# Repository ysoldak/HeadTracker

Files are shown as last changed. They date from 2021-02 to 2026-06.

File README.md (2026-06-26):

# Zero configuration auto-calibrating DIY head tracker

Head Tracker runs on [Seeeduino XIAO BLE Sense](https://www.seeedstudio.com/Seeed-XIAO-BLE-Sense-nRF52840-p-5253.html) and [Arduino Nano 33 BLE](https://store.arduino.cc/arduino-nano-33-ble) boards and connects to [OpenTX](https://github.com/opentx/opentx), [EdgeTX](https://edgetx.org) and [ETHOS](https://ethos.frsky-rc.com) radios via either wired (PPM) or wireless (Bluetooth) trainer link.

This project would not exist without [awesome work](https://github.com/tinygo-org/awesome-tinygo) by [TinyGo](https://tinygo.org) community that made [codding in Go for embedded systems](https://github.com/tinygo-org/tinygo) possible!

## Quick Setup

- **Buy** [Seeeduino XIAO BLE Sense](https://www.seeedstudio.com/Seeed-XIAO-BLE-Sense-nRF52840-p-5253.html) board
- **Flash firmware**
  - Plug-in the board to your computer
  - Double tap on `RST` button on the board (little one, near USB-C plug), `XIAO-SENSE` USB drive pops up
  - Download `ht_xiao-ble_x.x.x.uf2` from latest [release](https://github.com/ysoldak/HeadTracker/releases)
  - Copy the file to `XIAO-SENSE` USB drive
  - _Ignore operating system panic about USB drive was not properly ejected -- this is normal and expected_
  - USB drive disconnects itself and reboots (congrats! now you have your head tracker!)
- **Verify it works**
  - Re-connect XIAO BLE Sense board to your computer (Unplug and plug back again)
  - Open https://www.serialmonitor.org in Goggle Chrome browser and Connect to the board
  - Watch Head Tracker prints its status periodically (firmare version, bluetooth address and orientation)
- **Connect to your radio**
  - Pick up your radio with wireless trainer link (PARA, Bluetooth)  
    _all recent FrSky radios have wireless trainer that works; other radios may require [PARA Wireless module](https://www.horusrc.com/en/frsky-horus-x10-para-wireless-module.html) installed_
  - Connect XIAO BLE Sense board as a wireless trainer  
    _learn board's ID via [serial console](https://docs.arduino.cc/software/ide-v2/tutorials/ide-v2-serial-monitor) or by attaching little screen (see below) or by walking with your laptop, radio and board away from other bluetooth sources_
  - [Define mixers in your radio](doc/EthOS.md) from Trainer 1,2 and 3 channels to your desired model outputs  
    _you may want to [scale outputs to match rotation angels of the head tracker and your camera gimbal](doc/RadioConfiguration.md)_
- **Attach Head Tracker to your FPV goggles**  
  _see STL files in "case" folder, screen and button are optional_
- **Calibrate and Setup**  
  _nothing to do here, skip to the next item_
- **HAVE FUN!**  
    - _try our [fpv camera gimbal](https://cults3d.com/en/3d-model/gadget/micro-camera-gimbal-ysoldak) on your favourite model;_  
    - _check out [our shop](https://skygadgets.shop) for other cool gadgets._

## Video Tutorials
- [Connect the head tracker wirelessly to your radio](https://youtu.be/b292hyC5Ctk?t=280)  
  _watch full video to learn how to power the head tracker with a 1-cell lipo battery_

---

<table>
<tr><td>
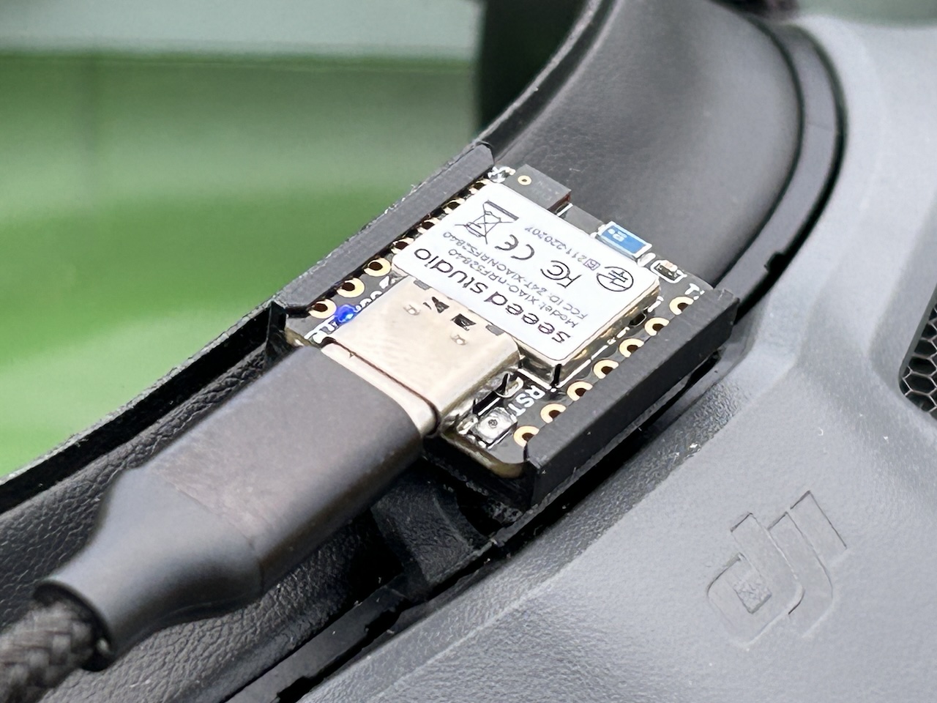
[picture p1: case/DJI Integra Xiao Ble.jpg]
XIAO on DJI Integra

</td><td>
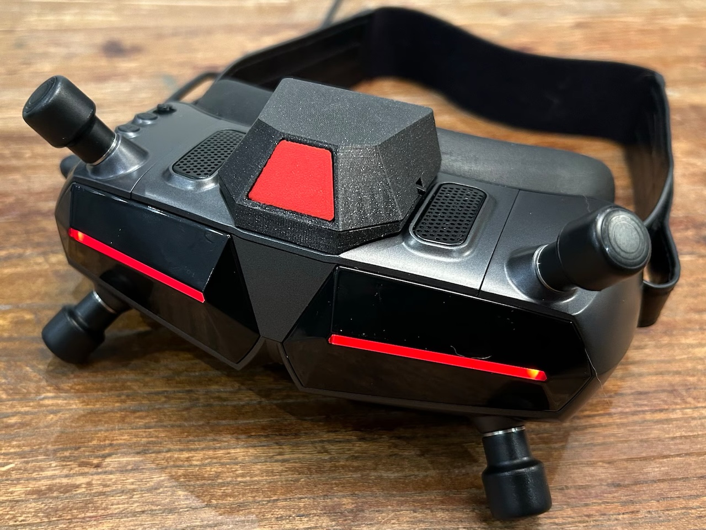
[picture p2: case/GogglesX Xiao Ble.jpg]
XIAO on Walksnail Googles X

</td></tr>
<tr><td>
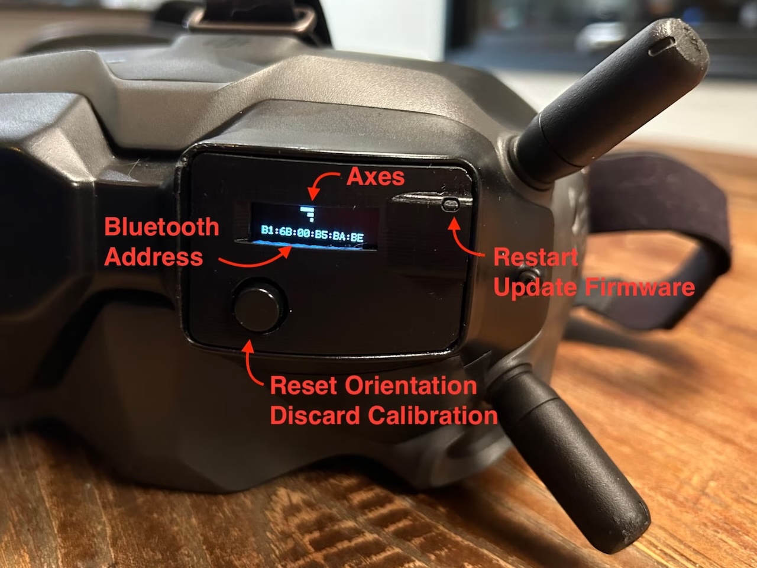
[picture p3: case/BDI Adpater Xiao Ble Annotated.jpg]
XIAO + SSD1306 128x32 on DJI Goggles

</td><td>
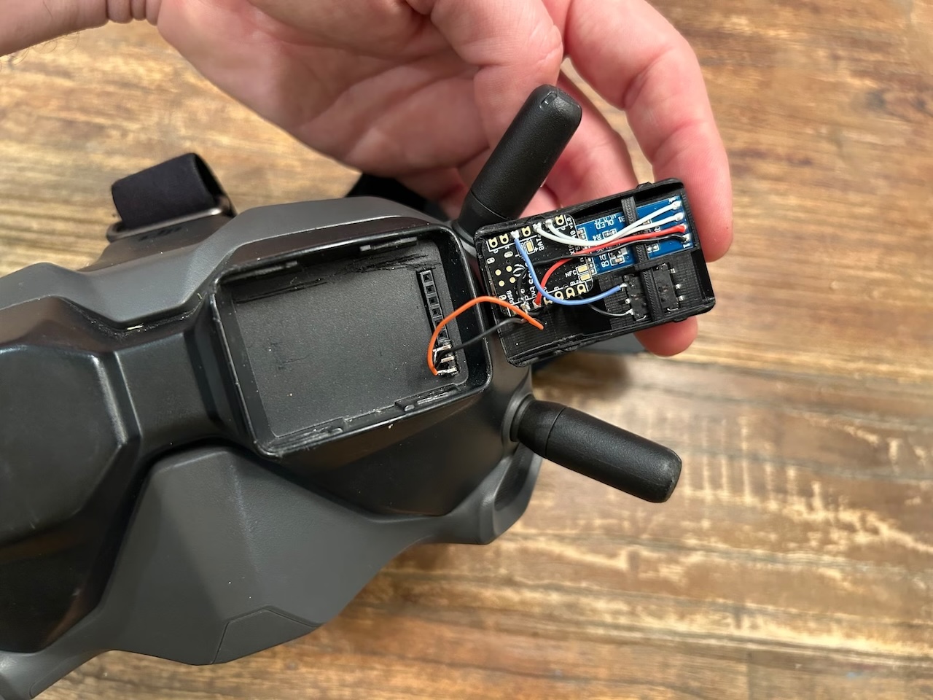
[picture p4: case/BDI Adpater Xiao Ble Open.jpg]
XIAO + SSD1306 128x32 on DJI Goggles, wiring

</td></tr>
</table>

## Camera Gimbal
Check our DIY 3D printed [Micro Camera Gimbal](https://cults3d.com/en/3d-model/gadget/micro-camera-gimbal-ysoldak) and [Low Profile Mod](https://cults3d.com/en/3d-model/gadget/low-profile-mod-for-micro-camera-gimbal) for it!  
Join our dedicated [Facebook group](https://www.facebook.com/groups/242161055041994)  

Also available [fully assembled or as a kit on our shop](https://skygadgets.shop/products/fpv-camera-gimbal-for-micro-servos).

<table>
<tr><td colspan="2">
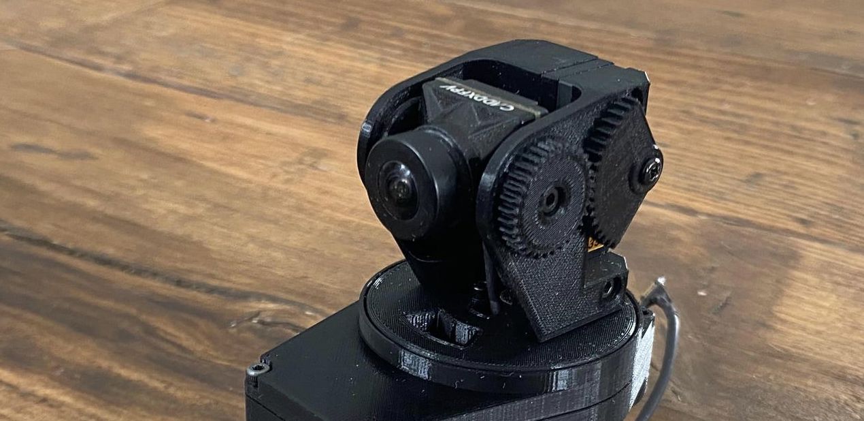
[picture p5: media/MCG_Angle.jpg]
Micro Camera Gimbal, angle

</td></tr>
<tr><td>
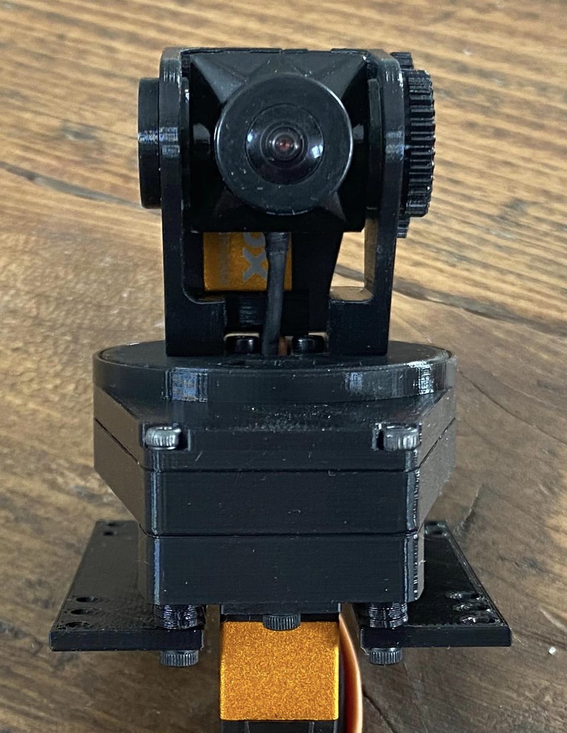
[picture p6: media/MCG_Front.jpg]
Micro Camera Gimbal, front

</td><td>
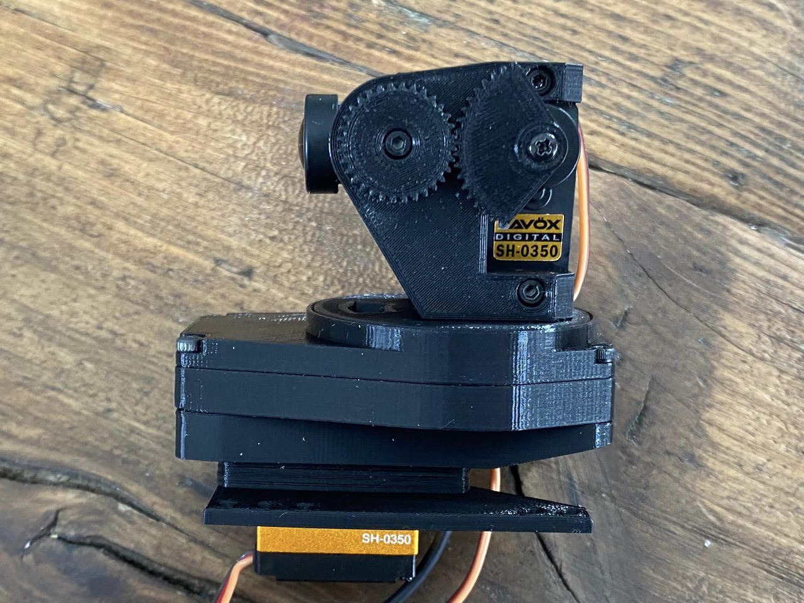
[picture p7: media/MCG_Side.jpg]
Micro Camera Gimbal, side

</td></tr>
</table>

## Tested radios
- FrSky X-Lite Pro (OpenTX)
- FrSky X20S Tandem (EthOS)
- [Radiomaster TX16S can be modified to have wireless trainer link](https://github.com/ysoldak/HeadTracker/discussions/31) and work with the head tracker

## Wiring reference
- **D2**: Orientation reset pin, use a button that connects this pin to **GND**
  - Press the button while head tracker is running to *reset its orientation*
  - Hold the button pressed on the head tracker power up to *factory reset* the board
- **D8**: PPM mode activation pin, solder it permanently to **GND** or use a positional switch
- **D10**: PPM signal pin, connect it to an audio jack tip and **GND** to the jack body
- **SDA&SCL**: I2C communication pins, connect them to 128x32 SSD1306 screen

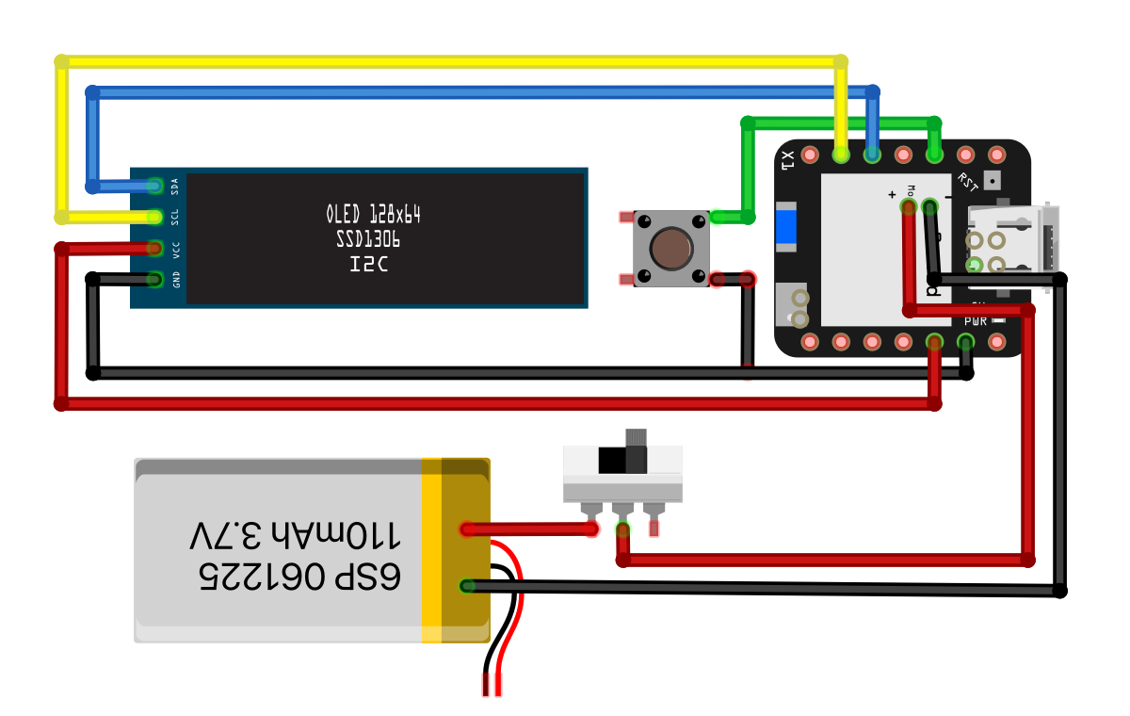
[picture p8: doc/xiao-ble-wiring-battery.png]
XIAO with screen, button and battery wiring diagram

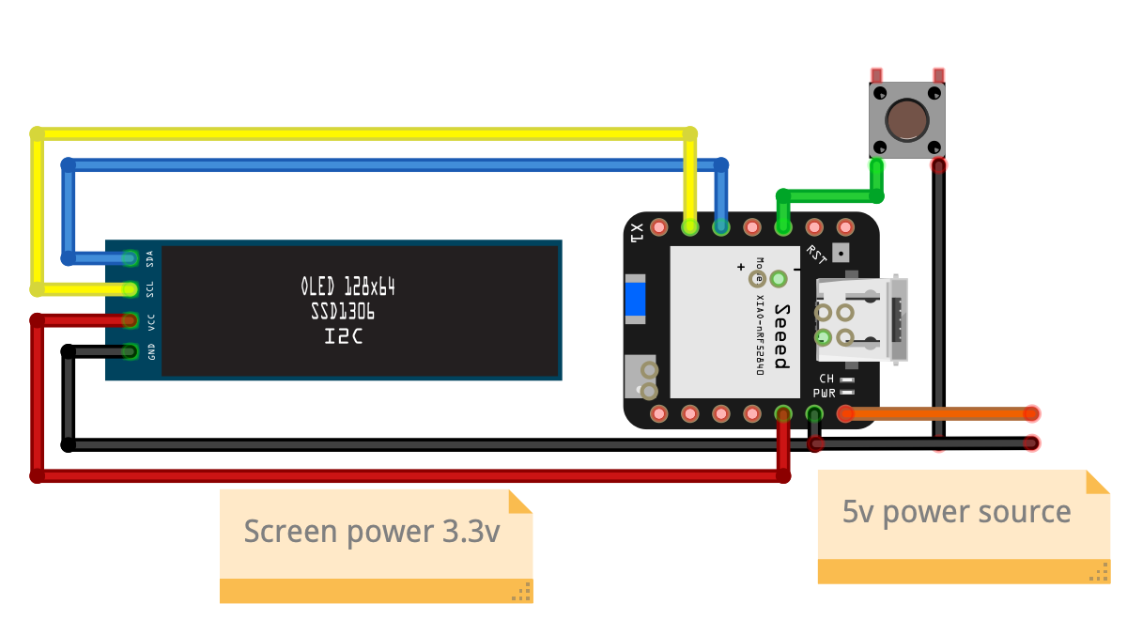
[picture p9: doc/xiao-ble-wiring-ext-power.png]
XIAO with screen and button wiring diagram


## Supported boards

Listed boards are perfect for a head tracker project, since they have both **IMU** for orientation and **Bluetooth** for connectivity.

**XIAO BLE Sense** is a tiny board with UF2 bootloader and SoftDevice (bluetooth driver) pre-flashed that makes it very easy to use.
The board is relatively new and may be harder to find. Please pay attention and order "Sense" variant, it has IMU.  
_Recommended for users w/o experience in embedded programming._

**Nano 33 BLE** is a larger board from Arduino that shall be easier to source. There are two variants of this board: "Nano 33 BLE" and "Nano 33 BLE Sense" -- both will work for this project. This board has no UF2 bootloader pre-flashed and a debug probe is required to flash UF2 bootloader to it.  
_Recommended for advanced users who have a debug probe (JLink or CMSIS-DAP compatible) and can use it._

For a long time, Nano 33 BLE was the only board supported. It has an additional sensor, magnetometer, that head trackers usually use to eliminate pan drift. In practice, however, magnetometer adds more problems than solves. Magnetometer is very sensitive to environment and tricky to calibrate properly. In this project we do not use magnetometer and have a good zero-configuration automatic continuous gyro calibration instead to solve the drift problem. Already after first 5 seconds the calibration is good enough to stop the drift.  

As of now, Nano 33 BLE board does not provide any benefit over XIAO BLE Sense. Instead, the later board is actually easier to use, thanks to pre-flashed UF2 bootloader and smaller size. In the future, just for fun, magnetometer support can be added but only if we can make calibration automatic and transparent for the user.

You have another nRF52840-based board with IMU and want to use it? File a feature request. Better yet, make a PR directly!

## Flash binary

### XIAO BLE Sense (Simple)
Connect the board to your computer, double-tap on RST button and copy `ht_xiao-ble_xxx.uf2` file to XIAO-SENSE usb drive.

### Nano 33 BLE (Advanced)
First, you shall [flash UF2 bootloader to the board](./doc/Nano33BLE.md). You only need to do this once for each new board.
Then connect the board to your computer, double-tap on button and copy `ht_nano-33-ble_xxx.uf2` file to NANO33BOOT usb drive.

## Use head tracker
Attach the head tracker to your FPV goggles.  
Power the head tracker via USB, 1 cell lipo battery or 5v source.  
> Hint: I've been using analog adapter bay on my DJI V1 goggles to source 5v. Now, I source power via USB-C cable connected to DJI Integra.  

### Bare
The head tracker is usable "bare", no extra accessories needed, not even a button.  
To reset the orientation without a button, simply **double-tap** the head tracker.  
> Hint: When the head tracker is mounted on your goggles directly, you can just double-tap your googles in any place to reset the orientation.

### LEDs
On start, board shall blink continuously blue, red and green/orange leds.
- Blue led indicates Bluetooth state and blinks while not connected, it switches to solid blue upon successful connection to your radio (see below);
- Red led indicates initial gyroscope calibration, you shall wait until the red led is off before use, normally no more than several seconds;
- Green/orange led indicates health of the head tracker and shall slowly blink during normal operation.

### Buttons
The head tracker records initial orientation on power up, place your goggles accordingly or reset orientation later by double-tapping the head tracker or by using a **reset orientation** button that can be wired to **D2** and **GND** pins.  
Keep **reset orientation** button pressed on power up to **discard calibration parameters** stored in flash memory.

### Display
If you have a LED `128x32` display added you your board (via I2C), the board's bluetooth address is displayed on it. Blinking ":" symbols indicate bluetooth connection status, like blue led. Upon start, while gyroscope is calibrating, you shall see head tracker version briefly on the screen. The version is then replaced by 3 horisonal bars, one for each axis: pan, tilt and roll.

### Bluetooth remote control (from v2.7.0)

The head tracker can be controlled remotely.  
Use [nRF Connect for Desktop](https://www.nordicsemi.com/Products/Development-tools/nRF-Connect-for-Desktop) or [nRF Connect for Mobile](https://www.nordicsemi.com/Products/Development-tools/nRF-Connect-for-mobile) to connect to your head tracker and send commands or do advanced configuration.

#### Send commands (0xFFC1)

Bluetooth characteristic `0xFFC1` (alt. `0xAFF2`) accepts following one-character commands:
- **Reset orientation** of the board by writing `R` to the characteristic;
- **Factory reset** the board by writing `F` to the characteristic;
- **Reboot** the board by writing `B` to the characteristic.

#### Set device name (0xFFD1)

Set device name by writing up to 16 bytes to `0xFFD1` characteristic.  
Default head tracker device name is "Hello".

#### Configure axes to channels mapping (0xFFD2)

Configure axes to channels mapping by writing 3 bytes to `0xFFD2` characteristic.
First (leftmost) byte configures mapping of the first axis to a channel, and so on. 

Each byte has format: `00IE0OOO`
- `0`   bit is not used,
- `I`   bit for inverted(1)/not inverted(0),
- `E`   bit for enabled(1)/disabled(0)
- `OOO` three bits for channel index offset (0-7),

Examples
- `0x10` means axis mapped to channel 1 (offset 0), enabled,  not inverted
- `0x11` means axis mapped to channel 2 (offset 1), enabled,  not inverted
- `0x25` means axis mapped to channel 6 (offset 5), disabled, inverted
- `0x34` means axis mapped to channel 5 (offset 4), enabled,  inverted

Default mapping: `0x101112` -- first 3 channels, enabled, not inverted

## Connect to radio

HeadTracker can work either in wireless (Bluetooth) or wired (PPM) mode.  
Bluetooth mode is active by default.

### Bluetooth
- Flash your board with a [release file](https://github.com/ysoldak/HeadTracker/releases)
- Connect to the board with a **Serial console** and make note of the board **address** (like: `7b:f5:1e:35:de:94`)
- [SSD1306 LED display](https://www.amazon.com/s?k=ssd1306+128x32+oled+i2c) can be connected (via I2C) to the board; in such case board address displyed there too
- In your radio, select Trainer mode **"Master/BT"**, wait a bit and click "[Discover]"
- Search for your board by address you noted earlier and **Connect** to it
- **Blue led** on the board shall turn **on** indicating successful connection
- Do not forget to configure **Trainer function** in your radio either on "Special Functions" screen of your model or on "Global Functions" of your radio setup.

### Wire
- Activate PPM trainer output by connecting **D8** and **GND** pins.
- Collect PPM signal from **D10** pin. (Audio jack tip shall be connected to **D10** and rest to **GND**)

## Related links
- [DIY-Head-Tracker](https://github.com/kniuk/DIY-Head-Tracker)  
  Original DIY head tracker for Arduino Nano with separate IMU board and PPM over cable
- [RC HeadTracker by Cliff](https://github.com/dlktdr/HeadTracker)  
  Another version of head tracker, based on Arduino Nano 33 BLE board.
- [Bluetooth Smart/BLE Crash Course](https://inductive-kickback.com/projects/bluetooth-low-energy/bluetooth-smartble-crash-course/)
- [Bluetooth low energy Characteristics, a beginner's tutorial](https://devzone.nordicsemi.com/nordic/short-range-guides/b/bluetooth-low-energy/posts/ble-characteristics-a-beginners-tutorial)

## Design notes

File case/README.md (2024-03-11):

## Xiao BLE Sense

The cases designed for Xiao BLE Sense board and SSD1306 128x32 display.  

### BDI Adapter

Head tracker receives power from analog bay.

Print `BDI Adpater Xiao Ble Case.stl` standing on USB-C connector hole side.  
Use double-size tape or a drop of rubber glue to attach the display to Xiao BLE.  
Place carefully little 3D printed boot button into respective place.  
Insert USB-C of Xiao BLE to respective hole and press the display in place.  
Press [Five Directions Navigation Button](https://www.amazon.se/gp/product/B07QM88HP2) into opening.  
Use `BDI Adpater Xiao Ble Lock.stl` to secure button and display.  
Insert power pins into analog bay connectors and insert the case into BDI adapter.

<table>
<tr><td>
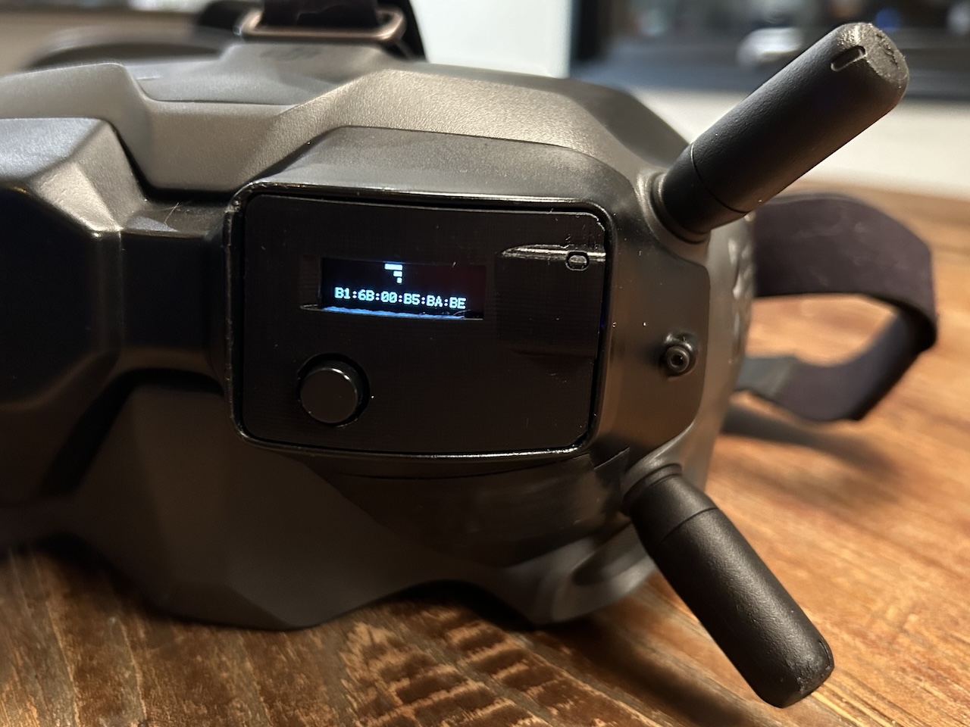
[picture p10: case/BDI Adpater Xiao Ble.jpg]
XIAO + SSD1306 128x32 on DJI Goggles

</td><td>
XIAO + SSD1306 128x32 on DJI Goggles, wiring
</td></tr>
</table>

### Walksnail Goggles X

Head tracker uses 1S battery for power.

Print `GogglesX Xiao Ble Case.stl` and `GogglesX Xiao Ble Base.stl` upside down.  
Insert display, XIAO board, power switch and [button](https://www.amazon.se/gp/product/B08FJ6GDZK) in places.  
Optionally, insert a piece of transparent 1.75mm filament as a light guide for RBG led of XIAO board.  
Add 1S battery, wire it via power switch.  
Close the case and secure with two short M2 screws.  
Place 3D printed orientation reset button cover in place, you may need to adjust the button a bit so click works.  
Attach the case to Googles X with help of double-sided tape.  

XIAO + SSD1306 128x32 on Goggles X

### DJI Goggles 2 / Integra

Head tracker gets power from goggle's USB-C port, connect with 0.25m cable.

Print `DJI Integra Xiao Ble Base.stl` and insert into top head strap loop, can be tight fit.  
Insert XIAO board into the bracket and connect to goggles with USB-C cable.

XIAO + SSD1306 128x32 on Goggles X

### FatShark Goggles

There is also an option to place Xiao BLE board with display on the right side of Fatshark googles.  
Power shall be sourced from googles themselves, 3.3v is available there.

Please check `XiaoBle2.3mf` file and pictures for placement and wiring hints.

<table>
<tr><td>
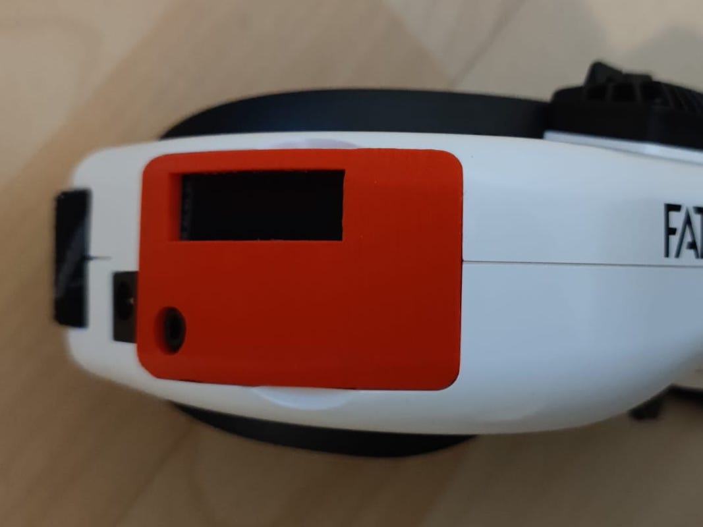
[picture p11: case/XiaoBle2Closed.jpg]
XIAO + SSD1306 128x32 on Fatshark Goggles

</td><td>
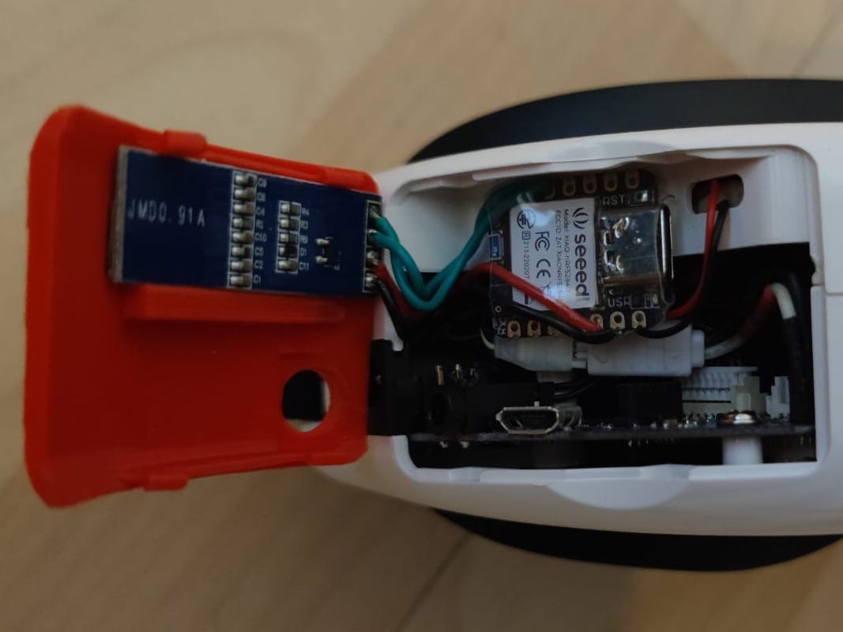
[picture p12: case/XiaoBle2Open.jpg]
XIAO + SSD1306 128x32 on Fatshark Goggles, wiring

</td></tr>
</table>

## Nano 33 BLE

Print `Nano33Ble-Main.stl` on its back, `Nano33Ble-Clip.stl` standing.

`Nano33Ble-Main.stl` has a hole above RGB LED (indicates Bluetooth connection state).  
Insert a piece of transparent fillament into it, for a light guide.

Glue a piece of little something on the case's reboot button (from inside or outside, your preference) to locate it easier.  
Board records orientation on boot, so rebooting is a way to reset orientation, no additional buttons needed.  
Note: Bluetooth connection will break on reboot just to restore quickly after.

Solder 2S balance plug to the board and press-fit it into case -- can power the board from FatShark's battery.  
There is a place for on/off switch, but that's optional.

<table>
<tr><td>
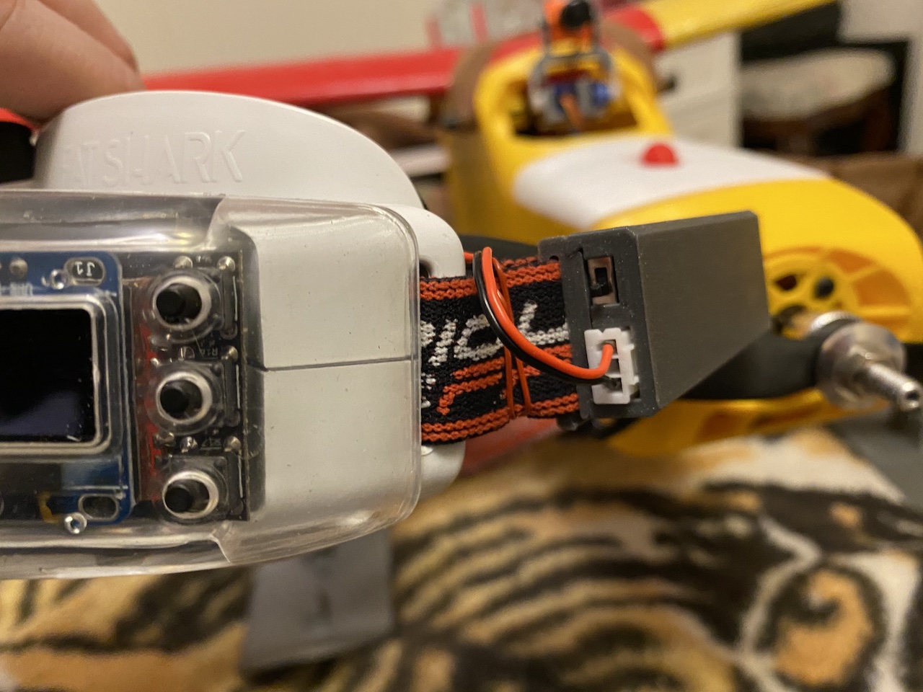
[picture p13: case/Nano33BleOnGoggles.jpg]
Nano 33 BLE on FatShark mounted on the left side

</td><td>
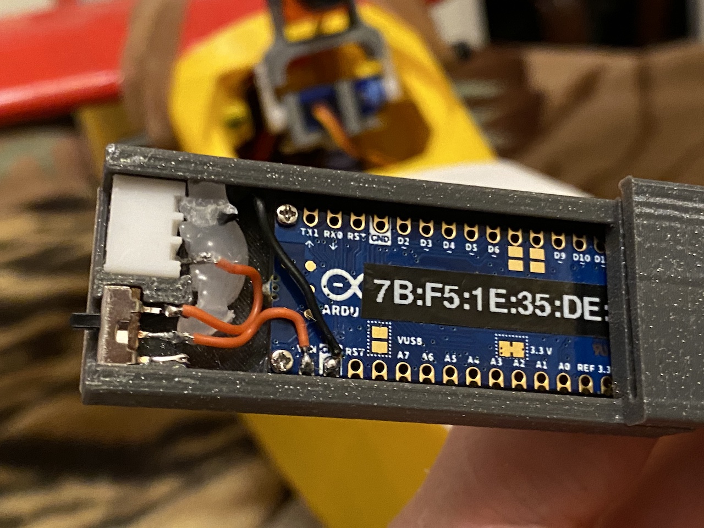
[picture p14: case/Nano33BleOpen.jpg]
Nano 33 BLE on FatShark, wiring

</td></tr>
</table>

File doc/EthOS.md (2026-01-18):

# EthOS 

Full configuration for the HeadTracker and [MicroCameraGimbal](https://cults3d.com/en/3d-model/gadget/micro-camera-gimbal-ysoldak) for [FrSky Tandem X20S](https://www.frsky-rc.com/product/tandem-x20s/) running [EthOS](https://ethos.frsky-rc.com).  

Following assumes you have HT pan servo connected to CH13 and tilt servo to CH14. CH15 is for roll, typically unused.  
HeadTracker runs on XIAO BLE board laying flat on goggles with USB-C facing to the right.  



Note: For HeadTracker mounted some other way `HT TrainerN` mixers will be different, since different trainer channels corespond to different HT axes in that case.  

See also [deep dive article](RadioConfiguration.md) if you want to understand where that % for mixers and outputs come from.

## Mixers

### HT Pot1 (Pan)
```
Name: HT 1
Active condition: Always On
Source: Pot1
Function Type: Add
...
Channels count: 1
Output1: CH13(TR3)
```

### HT Pot2 (Tilt)
```
Name: HT 2
Active condition: Always On
Source: Pot2
Function Type: Add
...
Channels count: 1
Output1: CH14(TR2)
```

### HT Trainer3 (Pan)
```
Name: TR3
Active condition: Always On
Source: Trainer3
Function Type: Add
...
Weight Up: 133%
Weight Down: 133%
...
Channels count: 1
Output1: CH13(TR3)
```
### HT Trainer1 (Tilt)
```
Name: TR1
Active condition: Always On
Source: Trainer1
Function Type: Add
...
Weight Up: 200%
Weight Down: 200%
...
Channels count: 1
Output1: CH14(TR1)
```

### HT Trainer2 (Roll)
```
Name: TR2
Active condition: Always On
Source: Trainer2
Function Type: Add
...
Weight Up: 200%
Weight Down: 200%
...
Channels count: 1
Output1: CH15(TR2)
```

### HT Kill Switch
```
Name: HT
Active condition: SG^
Source: 0
Function Type: Replace
...
Channels count: 3
Output1: CH13(TR3)
Output2: CH14(TR1)
Output3: CH15(TR2)
```

## Outputs

**Attention:** Output ranges must be set in either your Radio or model's Flight Controller, not both!  
If you connect yout pan and tilt servos directly to model's receiver, set output ranges in your radio.  
When pan and tilt servos connected to a Flight Controller, set respective ranges in FC's Outputs tab, leaving radio outputs be 100%.

### CH13 TR3
```
Name: TR3
Min: -150%
Max: 150%
```

## CH14 TR1
```
Name: TR1
Min: -133%
Max: 133%
```

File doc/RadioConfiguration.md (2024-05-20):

# How to configure your radio for the head tracker and a gimbal

### TL;DR
_(For the case of this head tracker and [Micro Camera Gimbal](https://cults3d.com/en/3d-model/gadget/micro-camera-gimbal-ysoldak) with Savöx SH-0350 servos)_  

**Output range pan**: 150% (732-2268us)  
**Output range tilt**: 133% (819-2181us)  
**Mixer weight pan**: 133%  
**Mixer weight tilt**: 200%

**Attention:** Output ranges must be set in either your Radio or model's Flight Controller, not both!  
If you connect yout pan and tilt servos directly to model's receiver, set output ranges in your radio.  
When pan and tilt servos connected to a Flight Controller, set respective ranges in FC's Outputs tab, leaving radio outputs be 100%.

See [EthOS](EthOS.md) article for the full configuration.

---

For the best experience with head tracking, you want your HT and camera be always aligned.
This concerns not only drift, but the deflection angle also.
It is quite annoying when you turn your head 90 degrees to the right and camera travels only 60 degrees same direction.
The opposite is annoying too. Let’s try and see how can we configure your radio to keep HT and camera in sync.

## Facts

Typical micro **servo throw** is `90deg` for standard range 988-2012us and `135deg` for extended range 732-2268us.  
Extended range is standard range multiplied by up to 1.5 and can be configured for any channel in most modern radios.  

Another important factor to keep in mind is **gear ratio** (for geared camera gimbals) for pan and tilt.  
For example, [Micro Camera Gimbal](https://cults3d.com/en/3d-model/gadget/micro-camera-gimbal-ysoldak) gear ratios are `2:1` for pan and `3:2` for tilt.

We shall use [Micro Camera Gimbal](https://cults3d.com/en/3d-model/gadget/micro-camera-gimbal-ysoldak)
with [Savöx SH-0350 servos](https://www.savoxusa.com/products/savsh0350-micro-digital-servo-16-36) in our calculations for the rest of this article.

## Calculations

### Head tracker output
The head tracker’s orientation (`-180` to `+180` each axis) is represented by three channels in standard range (988-2012us).  

### Output range
From servo throws for extended output range and gear ratios we conclude gimbal is capable of delivering `270deg` on pan and `202.5deg` on tilt.  
We do not need that much on tilt though and `1.33` output range shall be enough there giving us `180deg`.  

### Mixer weights
Since we have only `270deg` on pan vs. `360deg` that HT delivers, we need to scale trainer (input) channel for pan in radio so gimbal deflection angle matches the one of the head tracker.  
The pan input channel must be scaled by `1.33(=360/270)` and we do that by setting “`Weight:133%`” for respective mixer in radio powered by OpenTX-like firmware.  
Likewise, for tilt the weight value is `200%(=360/180)`.

## Conclusions and notes

That’s all, folks. Hope this helps you configure you radio for the best head tracking experience!

Note though, the exact values may vary a bit depending on which head tracker and camera gimbal you use and what outputs they are capable of.  
Servo throws can vary for brand, model and even individual servos to some extent. The above numbers shall help you started, adjust them for your case!

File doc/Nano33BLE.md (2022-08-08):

_This information is only actual for Arduino Nano 33 BLE boards, since Seeeduino XIAO BLE ships with UF2 bootloader pre-flashed._

## Flash UF2 bootloader on Nano 33 BLE board

You'll need a JLink \[EDU\] or any DAP-compatible [debugger](https://tinygo.org/docs/guides/debugging/#connecting-a-debug-probe) to flash [Adafruit's nRF52 bootloader](https://github.com/adafruit/Adafruit_nRF52_Bootloader) with soft device on Nano 33 BLE board.

Connect your debugger to the board and execute: `make flash-uf2-bootloader`.

_Tip: by default make uses JLink debugger, but there are `-dap` versions of above commands too._

---

## Optionally use S140 v7.3.0 soft device
_This step is not necessary and is provided for informational purpose only_

Adafruit pre-compiles UF2 bootloader with soft device version 6.1.1 for Nano 33 BLE, while newer (better?) soft device version 7.3.0 is available.

To compile UF2 bootloader with 7.3.0 soft device:
- Clone [Adafruit's nRF52 bootloader](https://github.com/adafruit/Adafruit_nRF52_Bootloader) repository
- Run `make BOARD=arduino_nano_33_ble SD_VERSION=7.3.0 all` to compile bootloader with 7.3.0 soft device
- Connect your board to JLink debugger
- Run `nrfjprog -f nrf52 --eraseall` to erase chip
- Run `nrfjprog -f nrf52 --program <path to arduino_nano_33_ble_bootloader-0.7.0_s140_7.3.0.hex>` to flash you board with bootloader and soft device
- Run `make TARGET=nano-33-ble-s140v7-uf2 flash` to flash HeadTracker to Nano 33 BLE board with 7.3.0 soft device

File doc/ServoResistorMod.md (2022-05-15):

# Increase throw of an analog servo

Common RC servo has throw of 45 degrees, each side (90 degrees total).
Some servos have total deflection of 120 or even 180 degrees, but they are usually expensive and/or hard to find.

And you generally want at least 180 degrees throw for pan (yaw) camera servo.

With this simple mod you can convert almost any analog 90 degrees servo to 180 degrees servo.
The idea is to tirck the servo contol circuit by increasing resistance of the servo potentiometer. 

Steps:
- Disassemble your servo and locate potentiometer;
- Measure resistance between potentiometer outer pins: `R0`;
- Calculate resistance `R1 = R0 * 0.6`;
- Solder an extra `R1` resistor between servo control circuit and each of outer potentiometer pins;
- Done!

Picture shows two 2.2kOhm resistors soldered to 3.7kOhm potentiometer.
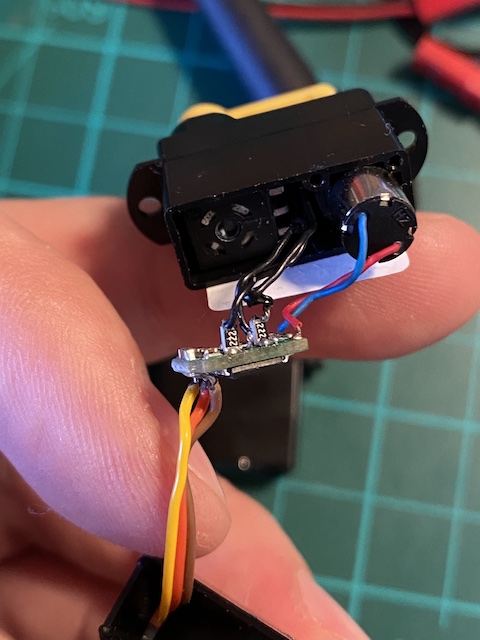
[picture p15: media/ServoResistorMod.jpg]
Servo resistor mod


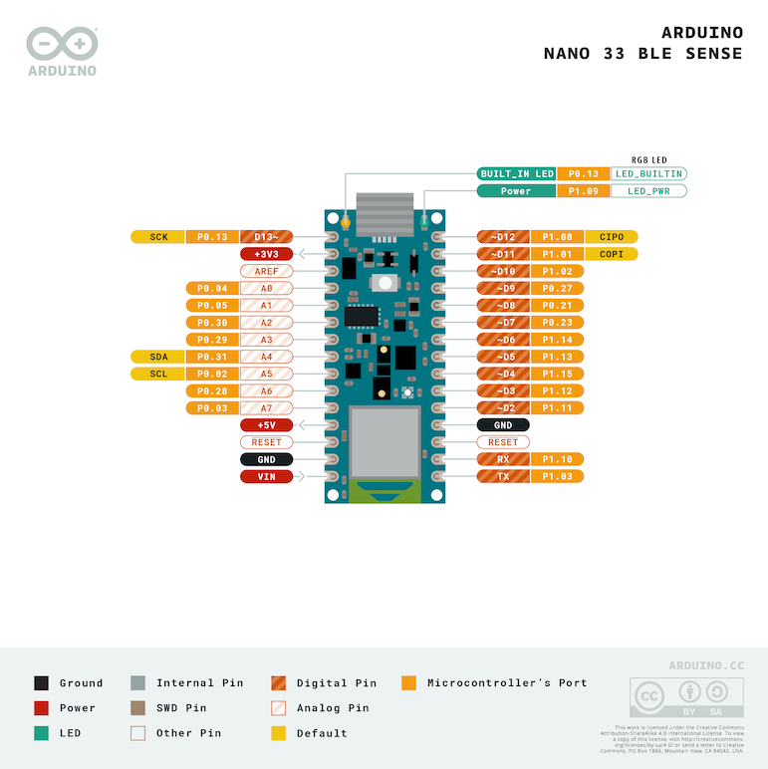
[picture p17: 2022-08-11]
doc/nano-33-ble-pinout.png

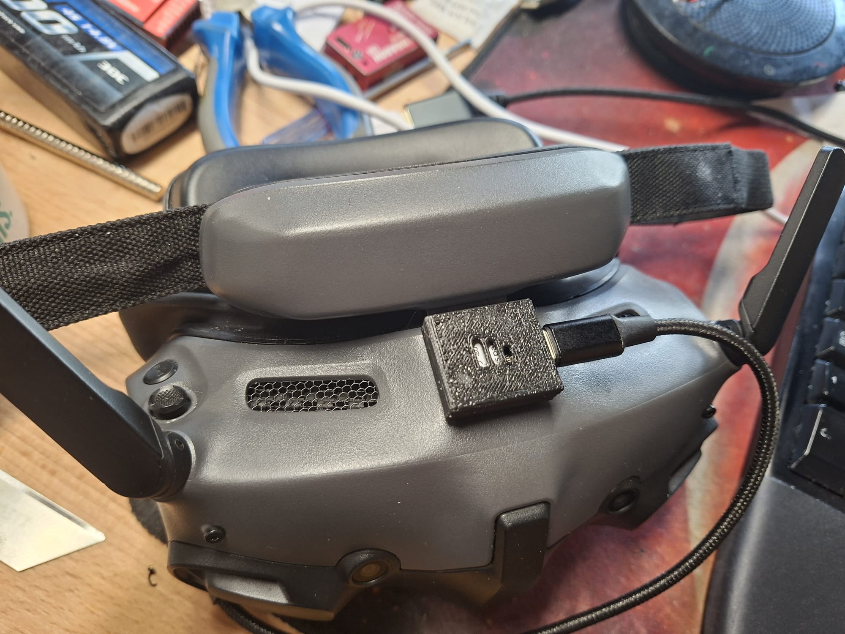
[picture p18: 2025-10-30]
case/xiao-micro-case-dji.jpg

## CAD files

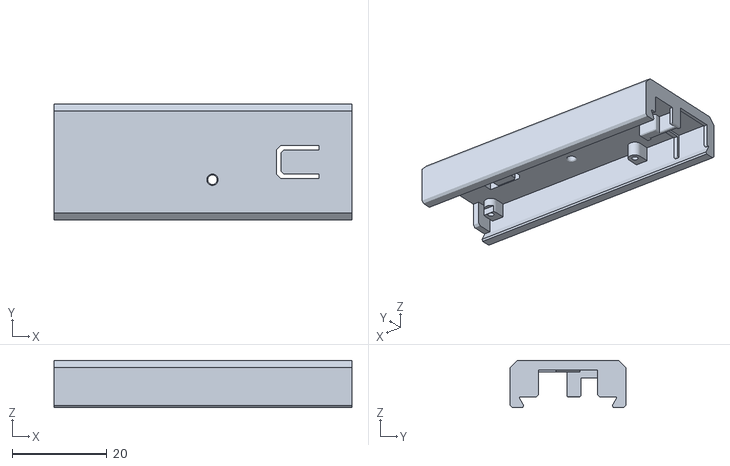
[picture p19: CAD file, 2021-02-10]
case/Nano33Ble-Main.stl
63.0 x 24.5 x 10.0

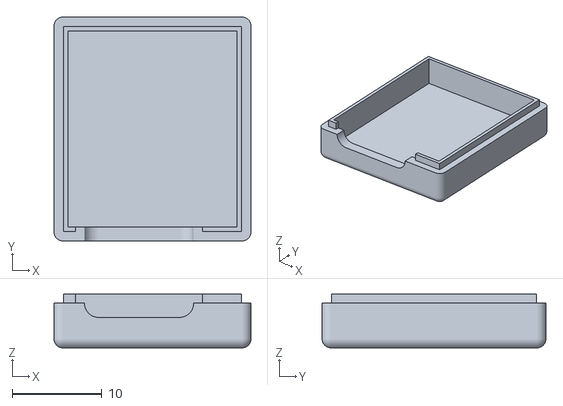
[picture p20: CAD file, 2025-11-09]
case/xiao-micro-case-base-wired.stl
22.0 x 25.0 x 6.00

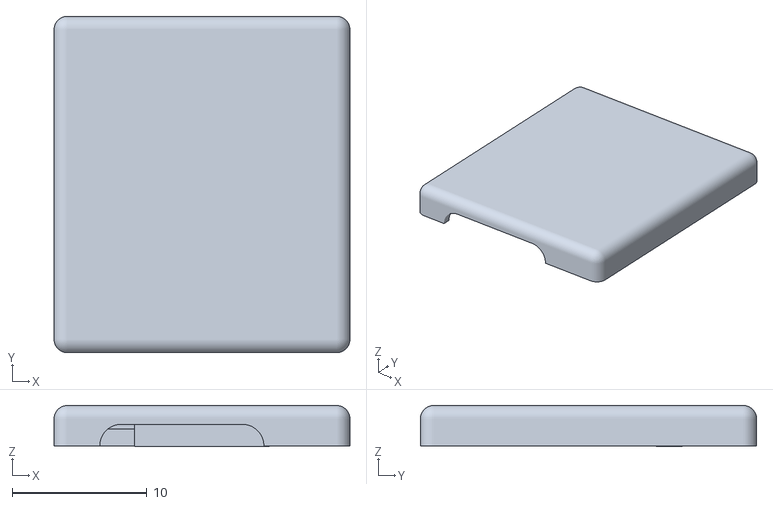
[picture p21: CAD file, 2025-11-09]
case/xiao-micro-case-lid-wired.stl
22.0 x 25.0 x 3.05

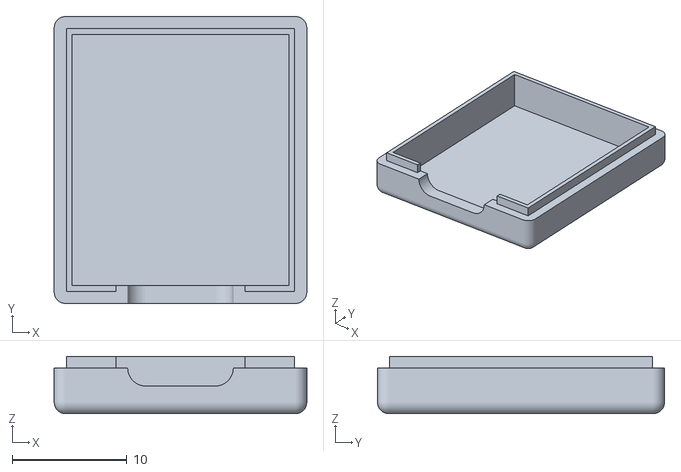
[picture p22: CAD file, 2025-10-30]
case/xiao-micro-case-base.stl
22.0 x 25.0 x 5.00

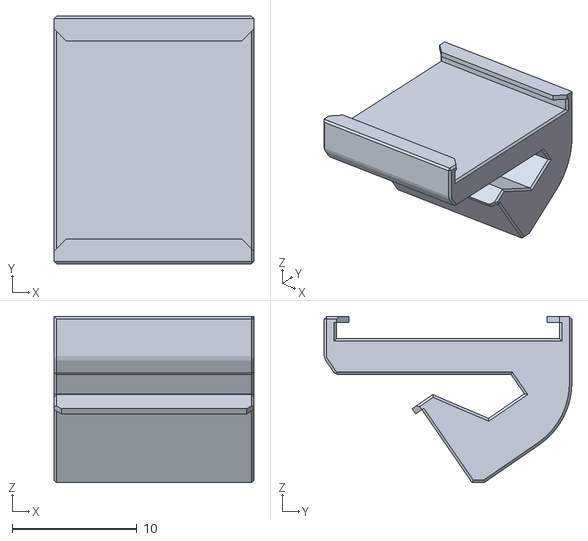
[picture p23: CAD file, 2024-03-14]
case/DJI Integra Xiao Ble Base Forward.stl
16.0 x 19.8 x 13.3

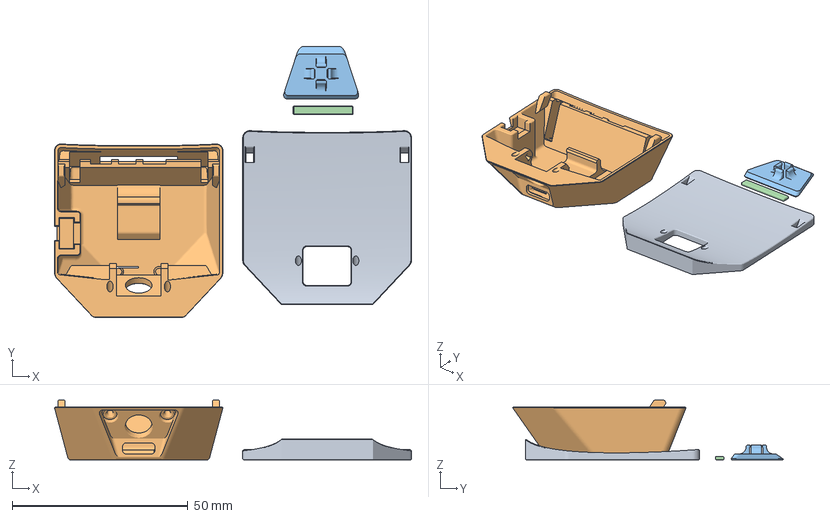
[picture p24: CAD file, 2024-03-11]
case/GogglesX Xiao Ble.3mf
101.5 x 77.0 x 17.0 mm
GogglesX Xiao Ble Base.stl
GogglesX Xiao Ble Case.stl
GogglesX Xiao Ble Button.stl
GogglesX Xiao Ble Lock.stl

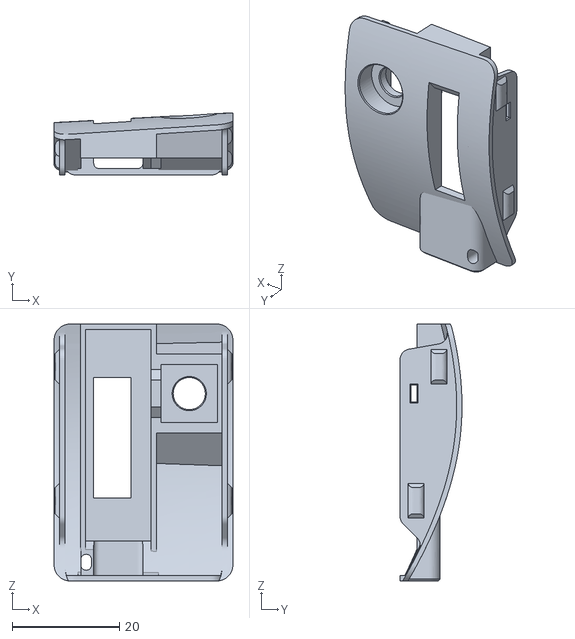
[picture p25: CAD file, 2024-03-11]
case/BDI Adpater Xiao Ble Case.stl
33.4 x 11.6 x 48.0

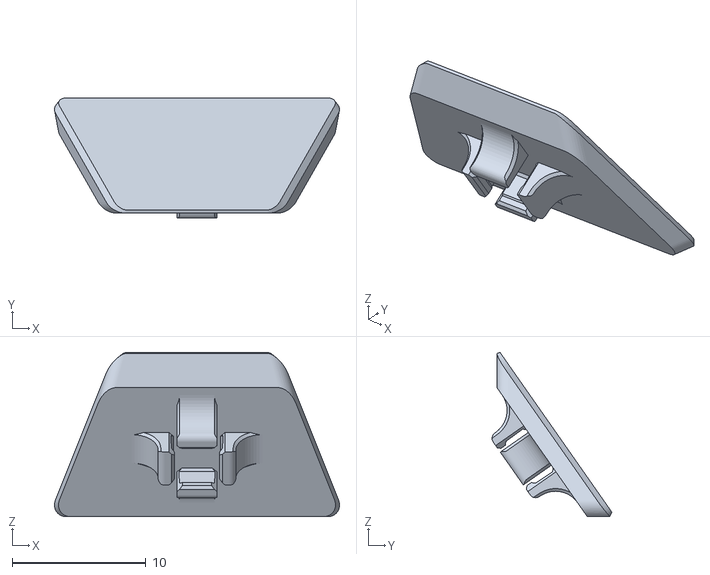
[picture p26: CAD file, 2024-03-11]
case/GogglesX Xiao Ble Button.stl
21.3 x 8.97 x 12.3

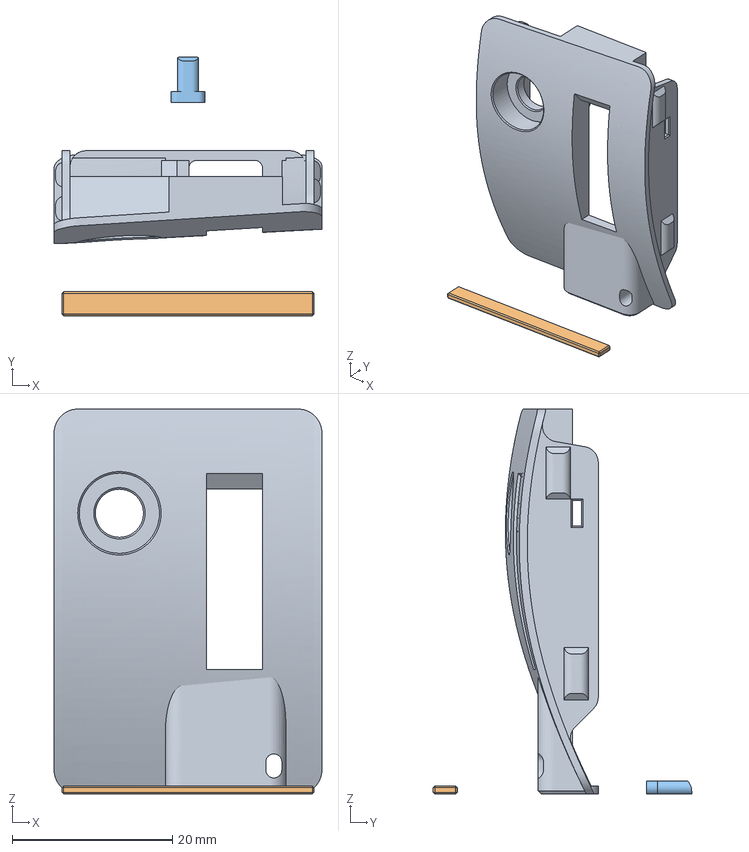
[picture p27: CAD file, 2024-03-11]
case/BDI Adpater Xiao Ble.3mf
33.4 x 32.2 x 48.0 mm
BDI Adpater XIAO Case Body.stl
BDI Adpater XIAO Case Lock.stl
BDI Adpater Xiao Ble Button.stl

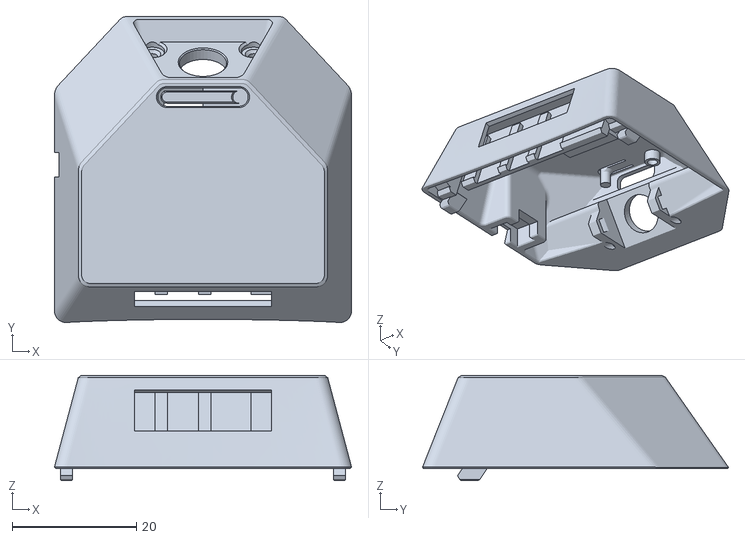
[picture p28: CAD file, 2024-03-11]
case/GogglesX Xiao Ble Case.stl
47.9 x 49.3 x 17.0

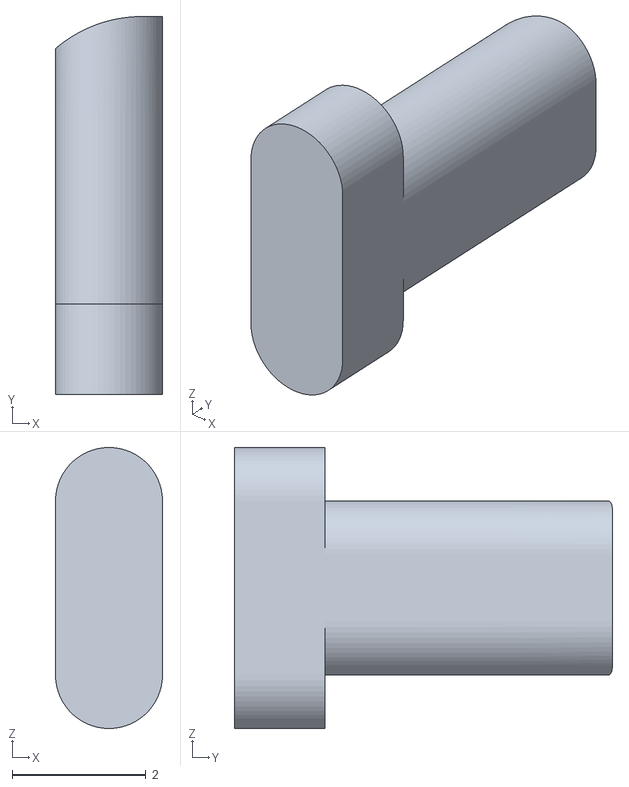
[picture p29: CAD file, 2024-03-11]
case/BDI Adpater Xiao Ble Button.stl
1.60 x 5.65 x 4.20

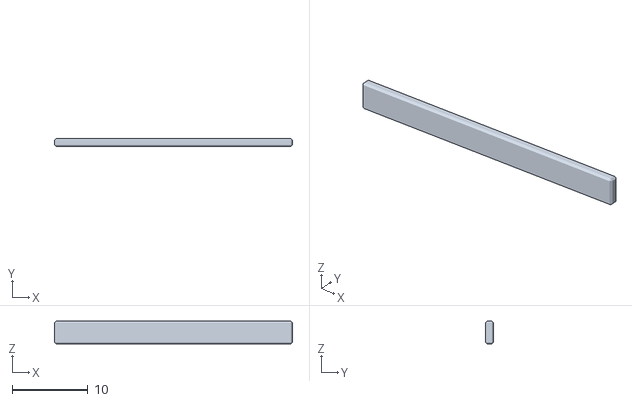
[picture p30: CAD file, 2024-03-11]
case/BDI Adpater Xiao Ble Lock.stl
31.4 x 1.00 x 3.00

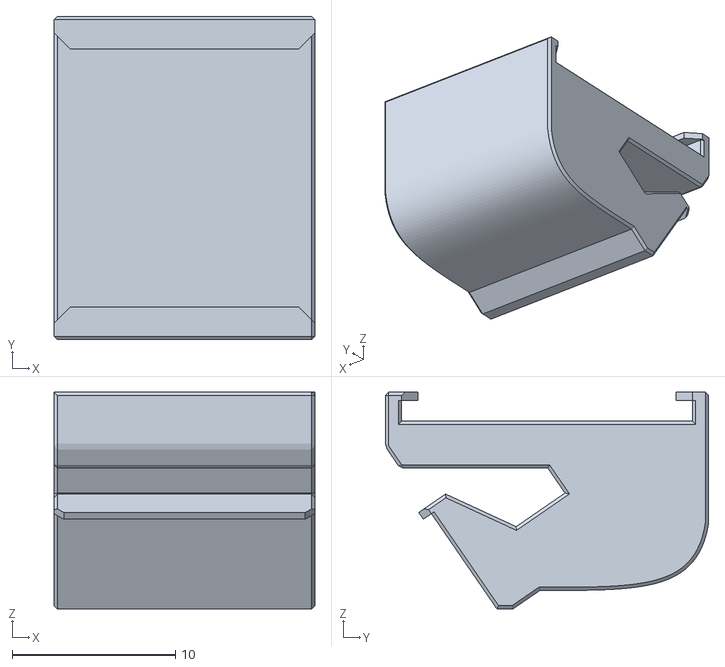
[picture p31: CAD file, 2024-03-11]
case/DJI Integra Xiao Ble Base.stl
16.0 x 19.8 x 13.3

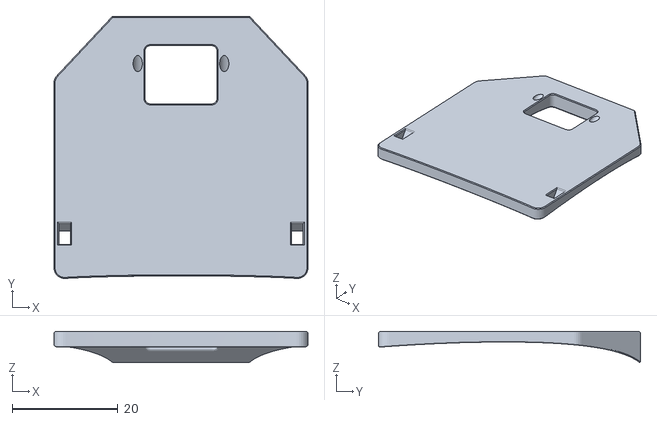
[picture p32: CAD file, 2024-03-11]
case/GogglesX Xiao Ble Base.stl
48.0 x 49.5 x 5.88

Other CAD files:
case/xiao-micro-case-lid.stl
case/GogglesX Xiao Ble Lock.stl
case/XiaoBle2.3mf
case/Nano33Ble-Clip.stl
case/BDI Adpater Xiao Ble.f3d
case/DJI Integra Xiao Ble.f3d
case/GogglesX Xiao Ble.f3d

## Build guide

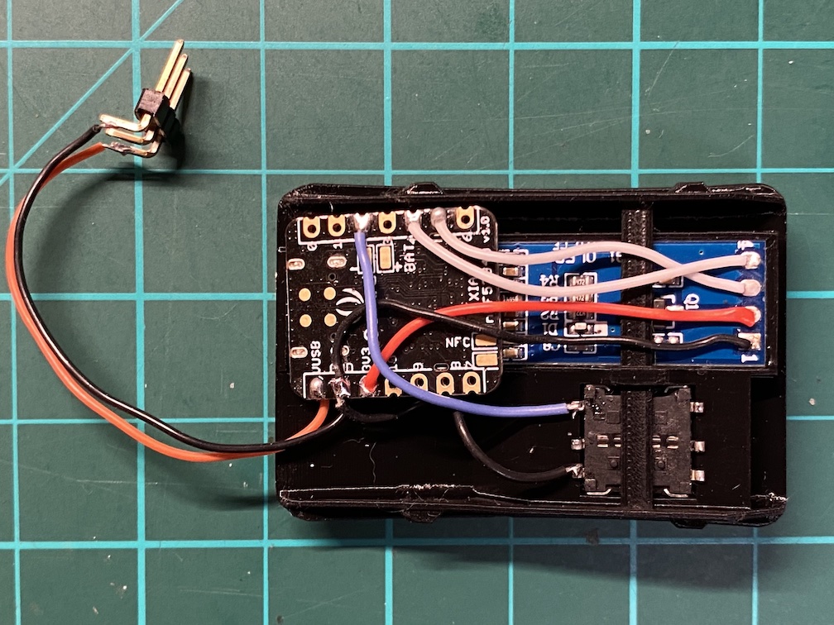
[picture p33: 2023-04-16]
doc/xiao-ble-wiring.jpg

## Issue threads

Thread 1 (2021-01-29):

Calibration routine in the main sketch

ysoldak, 2021-01-29:
Shall be possible to open serial console and initiate calibration.
Eliminates separate sketch.
Start with outputting calibration parameters for copy-paste, make it possible to store in EPROM later.

ysoldak, 2022-05-12:
Not actual anymore after switching to Go

Closed 2022-05-12.

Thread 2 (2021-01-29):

Control via Bluetooth

ysoldak, 2021-01-29:
Since the board has bluetooth, why don't use it for configuration.
Would be handy at field and for calibration "in-situ".

ysoldak, 2021-02-12:
Can perhaps use web_bluetooth
https://github.com/armsp/nano-33-ble-gen/tree/master/bluetooth/web_bluetooth

ysoldak, 2022-08-30:
Not actual anymore, since we target zero-configuration in the HT itself. All adjustment shall be done in user's radio. Or with jumper wires / switches.

Closed 2022-08-30.

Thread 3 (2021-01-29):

Initial pairing is pain

ysoldak, 2021-01-29:
Once connected, it's perfect, can power cycle the board -- it re-connects all good. And stays connected.
But to make the board connect to the radio the first time can be pain.
I expect there are some bugs in ArduinoBLE library that shall be fixed or code in the main loop re-arranged to please FrSky radios.
Shall debug and see.

ysoldak, 2021-02-01:
After some experiments, it seems like Arduino's bluetooth stack is actually OK.

Instead, the radio's bluetooth that may end up in some limbo state if you try to "[Clear]" connection and then connect again in hope to speed up connection after powering off radio and turning it on before a flight.

Just wait, let radio to boot up its bluetooth stack, discover head tracker board and connect to it.
So far, once paired, waiting was the best approach and definitely better than jamming radio with constant requests to clear connection and connect again.

ysoldak, 2021-02-02:
After flashing a new version, board sometimes [changes address](https://github.com/ysoldak/HeadTracker/issues/6) and this breaks bluetooth plairing. No reason to wait for eventual connection (as advised), that will never happen.

Shall be no-issue for day-to-day use (no flashing a new version), but good to keep in mind.

ysoldak, 2022-05-12:
Not actual anymore after switching to Go

Closed 2022-05-12.

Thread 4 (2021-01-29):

Upload STL and STEP files for the board case

ysoldak, 2021-01-29:
I have them, just need to make a final version and upload here (or Thingiverse and link there).

Closed 2021-02-01.

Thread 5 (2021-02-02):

Improve orientation by sensor fusion

ysoldak, 2021-02-02:
[Madgwick](https://github.com/arduino-libraries/MadgwickAHRS) library, for example.

This will use gyro as a base for orientation, fused with accelerometer and magnetometer to fix drift.
https://youtu.be/6qV3YjFppuc

ysoldak, 2021-02-02:
https://courses.cs.washington.edu/courses/cse474/17wi/labs/l4/madgwick_internal_report.pdf

ysoldak, 2021-02-02:
https://blakejohnsonuf.com/project/#IMU

Closed 2021-02-10.

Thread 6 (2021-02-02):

Board sometimes changes address

ysoldak, 2021-02-02:
After flashing new version, the board sometimes changes its bluetooth address (displayed in radio). This breaks pairing and forces operator to do that initial pairing again, and that’s [pain](https://github.com/ysoldak/HeadTracker/issues/3).

This issue affects development, but not regular usage, so kind of low prio, still annoying, would be great to fix this.

ysoldak, 2022-05-12:
Not actual anymore after switching to Go

Closed 2022-05-12.

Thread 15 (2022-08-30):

E73-2G4M08S1C+MPU6500+QMC5883L

01Space, 2022-08-30:
Hi，
Can you add firmware support for e73-2g4m08s1c + mpu6500 + qmc5883l board?
Others have developed a head tracker using ESP + mpu9250 with lower cost.
https://github.com/ScrumPilot616/HeadTracker

ysoldak, 2022-08-30:
No. I don't have the hardware mentioned and cost was never the priority.
Zero configuration, small size, minimum soldering and ease to flash new versions -- these are the priorities of this project.

Closed 2022-08-30.

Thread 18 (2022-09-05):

Feature suggestion: SBUS output signal

MrMap, 2022-09-05:
Regarding HT output formats:
Presently there is BT and PPM; **SBUS** could be an additional format.
SBUS would be useful for all Radiomaster & Jumper users that do not have BT and are OK with a wire connection between HT and radio (servo cable type). They could use SBUS wire connection between HT and radio serial port 1/2 (used as trainer port) - and even power the HT via the very same wire (supply HT power from radio serial port).

Two benefits over PPM:
Digital serial protocol - no jitter.
HT power can supplied without need of USB.

Here is some info on the SBUS serial protocol:
https://github.com/uzh-rpg/rpg_quadrotor_control/wiki/SBUS-Protocol

Nice to know:
For test purposes this gadget, found in many RC pilots toolbox, can display the values transmitted on all the SBUS channels:
https://www.isdt.co/down/pdf/BG-8S_en.pdf

ysoldak, 2023-06-14:
**Notes harvested from internets**

The SBUS protocol uses an inverted serial logic with a baud rate of 100000, 8 data bits, even parity, and 2 stop bits. The SBUS packet is 25 bytes long consisting of:
```
	   Byte[0]: SBUS header, 0x0F
	   Byte[1 -22]: 16 servo channels, 11 bits each
	   Byte[23]
	   Bit 0: channel 17 (0x01)
	   Bit 1: channel 18 (0x02)
	   Bit 2: frame lost (0x04)
	   Bit 3: failsafe activated (0x08)
	   Byte[24]: SBUS footer
```
Note that lost frame is indicated when a frame is lost between the transmitter and receiver. Failsafe activation typically requires that many frames are lost in a row and indicates that the receiver has moved into failsafe mode. Packets are sent approximately every 10 ms or 20 ms, depending on the system configuration.

Note on CH17 and CH18: Channel 17 and channel 18 are digital on/off channels. These are not universally available on all SBUS receivers and servos.

FrSky receivers will output a range of 172 - 1811 with channels set to a range of -100% to +100%. Using extended limits of -150% to +150% outputs a range of 0 to 2047, which is the maximum range acheivable with 11 bits of data.

Because SBUS is a digital bus format, it is an excellent means of receiving pilot commands from a transmitter and an SBUS capable receiver. If SBUS servos are used in the aircraft, SBUS is also an excellent means of sending actuator commands - servo commands can often be sent with lower latency and, by only using a single pin to command up to 16 servos, additional microcontroller pins are freed for other uses.

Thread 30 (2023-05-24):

A noob question about battery

donne1226, 2023-05-24:
I wanna make it without the screen.
What is the hourly power consumption？ I wanna use it about 6 - 10 hours. Can you recommend what the battery capacity should be?

dlktdr, 2023-05-24:
This sounds very familiar to an issue I had with the our firmware in the past if the module you have in your radio isn't the PARA module. If you have the older non-para module it will connect but no data is sent. The older module required encryption to be enabled.

Yuri, here is all the info we found on that issue https://github.com/dlktdr/HeadTracker/issues/22 including some Bluetooth scans.

Although if this is the case then it probably never would have worked even once. Just a thought :)

donne1226, 2023-05-25:
Yes Cliff, I am using the Frsky non-PARA module.

I am sure it worked a few times because I can see value changes on the trainer page. When I did the range test, the radio played 'trainer signal lost' and 'trainer signal recovered'. by the way, I found that the connection range is very short and disconnects at less than one meter.

ysoldak, 2023-05-25:
> by the way, I found that the connection range is very short and disconnects at less than one meter.

I’d assume the board has real tiny antenna and not designed for longer distances.
In my experience the range was more like two meters or so. But then, I don’t see that as a problem, why would your goggles be more than a meter away from your radio :)

ysoldak, 2023-05-25:
Alright, so apparently there are more than one type of bluetooth module that can be installed in radios.

The correct one (works with this head tracker and equal to installed in recent FrSky radios) is called [PARA Wireless Module](https://www.horusrc.com/en/frsky-horus-x10-para-wireless-module.html).

And this is [WRONG module](https://www.horusrc.com/en/frsky-transmitter-horus-x12s-bluetooth-module.html), do NOT buy and install it, will not work, at least not with this head tracker.

donne1226, 2023-05-26:
Alright then.  Thanks anyway. Using such a small board for the head tracker is a great idea！

ysoldak, 2023-05-26:
You can still use XIAO with your radio, two options:
- use `PPM` (wired connection)
- use `Arduino Nano 33 BLE` on the radio side as a helper module (from Cliff's project), HT will connect to it wirelessly (same protocol) and helper module will connect to your radio via SBUS or PPM.

dlktdr, 2023-05-26:
@donne1226 You could also replace the module in your radio with an ESP board (Wroom32, pico32 or c3mini). You can flash some code that emulates the PARA module that should work with this Head Tracker too.

I was looking for a way to remove the dependency of using Frsky modules 😉 It's not super easy to remove the module after it's soldered in, so @ysoldak options are probably the better choice if your not up for a bit of a challenge. Code is here https://github.com/dlktdr/BTWifiModule

ysoldak, 2023-05-26:
Nice, @dlktdr !
As a XIAO fanboy, I want to hint on XIAO ESP32C3 board: https://www.seeedstudio.com/Seeed-XIAO-ESP32C3-p-5431.html

dlktdr, 2023-05-26:
👍 Should (... hopefully) just have to change these pin numbers to make it work :) https://github.com/dlktdr/BTWifiModule/blob/245e0557da3e2e1c900752333933942caf901a6d/src/defines.h#L26C1-L27

I don't have one of these yet. Also like the size of the XIAO boards, only have the NRF versions currently. I might have to pick one up. I don't want to get too far off topic here, let me know if you ever give it a try 😉

donne1226, 2023-05-26:
I'm willing to tinker with the XIAO module to make it functional, but I don't think it's suitable for widespread promotion. First, it's a bit too expensive. Second, there are some technical difficulties.

In the past, I made a tutorial video based on Cliff’s project. Lots of people made their own head tracker modules, which was great!

I found this project a few days ago, and the XIAO board is smaller and cheaper than an Arduino. It's perfect for a standalone module with a built-in battery, so we can get rid of all wires. If you can make it work, I believe that more people will use it.

ysoldak, 2023-05-26:
Yes, I can try, have couple of such boards here and can test it by plugging in to PPM on my radio.

ysoldak, 2023-05-26:
FYI, gentlemen, to make information we discussed here more visible, I've created a [discussion with options for people w/o built-in PARA module](https://github.com/ysoldak/HeadTracker/discussions/31).

Closed 2023-05-26.

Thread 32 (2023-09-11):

Enhancement request for higher battery charge current using Seeed Sense board

puresims, 2023-09-11:
The Xiao BLE has a built in charger for a lipo, but it default charges at 50ma. It can be made to charge at 100ma but has to be done in code.

From the seeedstudio wiki ref: [HERE](https://wiki.seeedstudio.com/XIAO_BLE/?fbclid=IwAR0pTvYtI4JhvGIhpe3tak5j41LQMdeb710NNxy9-Qd78alAKXI8TqYHG3c)

**Battery Charging current**
The battery charging current is selectable as 50mA or 100mA, where you can set Pin13 as high or low to change it to 50mA or 100mA. The low current charging current is at the input model set up as HIGH LEVEL and the high current charging current is at the output model set up as LOW LEVEL.

**Low Charging Current**
```
void setup(){
pinMode (P0_13, OUTPUT);
}
void loop() {
digitalWrite(P0_13, HIGH);
}
```

**High Charging Current**
```
void setup(){
pinMode (P0_13, OUTPUT);
}
void loop() {
digitalWrite(P0_13, LOW);
}
```

ysoldak, 2023-09-11:
Guys, you can try a binary build that shall enable high charge current. Let me know if it works as expected.
Download "binaries" here: https://github.com/ysoldak/HeadTracker/actions/runs/6151924908

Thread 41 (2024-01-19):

Show battery state

ysoldak, 2024-01-19:
Since many assemble this head tracker with 1S LiPo battery, it would be beneficial for them to see battery state.

We can show battery state on boot splash screen and on normal operation screen.

Closed 2024-01-20.

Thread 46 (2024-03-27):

Configuration via Original HeadTracker GUI

bishko, 2024-03-27:
Is it possible to have a firmware that would be compatible with the original HeadTracker from @kniuk so that the GUI can be used?

I'm asking this querstion for two reasons:

1) The GUI allows you to chose which channel you want to use for each axis.

2) It allows you to select between a HT transmitter and receiver.

I have installed the Arduino Nano 33 BLE in my radio because and it is working as a receiver, but it is waiting for a transmitter to be able to connect to it and receiver the information. I belive that this does not run the same way or am I mistaken? Since there is no GUI, I don't know how this is configured.

Would be nice if you can clarify these things and maybe make it compatible with the original HeadTracker at least as a trasmitter.

Maybe having two firmware, one for TX and one for RX would also be a great alternative.

ysoldak, 2024-03-28:
Hi @bishko

Short answer: no, not possible, and no plans to implement this.

Long answer:
Let me unpack the short answer here.

I see there is some confusion about different open source head tracker projects we have now.
To my knowledge, here are 3 major HT projects on GitHub:
- [Original DIY Head Tracker](https://github.com/kniuk/DIY-Head-Tracker) by Denis Frie
- [Feature rich Head Tracker](https://github.com/dlktdr/HeadTracker) by Cliff
- [Zero configuration Head Tracker](https://github.com/ysoldak/HeadTracker) by Yurii Soldak, your's truly

Denis Frie started original head tracker project in 2012, it run on Arduino Nano board and requires a separate IMU board connected to the Nano board. It is a wired solution. This head tracker was presented on RC Groups and inspired many, including us with Cliff to try and make our own, improved HTs.

Some time in end of 2020, both me and Cliff had an idea to implement a head tracker on Arduino Nano BLE board: it has both IMU and Bluetooth on board, so no extra soldering was required and, potentially, we could try and connect it to our radios via wireless trainer link (bluetooth). So we naturally joined forces and had shortly had first working version, with both orientation and bluetooth link working!

Almost from start though, we had different visions on how to proceed. I guess, Cliff wanted the best HT that works for everyone, means lots of features, a nice desktop configurator for calibration and settings. The real deal, THE project.

I, on my part, just wanted something simple that works for me (and great if for someone else too), and easy to maintain, very opinionated. I did not want this to become THE project for me, I'd rather go build and fly my planes :D So no configurator app, no manual calibration -- all, unavoidable and minimal, configuration happens in the radio. Then I've added a mini display, because it's fun and a centering button, because why not. But they both are extras, not needed for HT to work.
Then I've switched to XIAO BLE Sense board to 1) simplify flashing with drag-n-drop and 2) because I like how small XIAO is.
XIAO has no magnetometer (compass), that is believed to be absolute necessary to avoid pan drift. Formally speaking it is true, in practice though, the drift can be compensated in software good enough to be unnoticeable during regular 5-15 mins FPV sessions. Without magnetometer, the last reason to have a configurator app (for magnetometer calibration, tedious and unreliable task) disappeared for me.

So, by design, this head tracker project has no configurator and does not support any and will not in the future, it's just against the project's idea/philosophy.

Now, to your actual questions:

1. This HT always outputs on first 3 channels. It is VERY easy to MIX these three trainer channels (TR1,2,3) to any random output channel in radio (I use CH13 for pan and CH14 for tilt). So there is absolutely no reason to have a separate configurator app for that. Please see an [article how you can configure your OpenTX radio to achieve that](https://github.com/ysoldak/HeadTracker/blob/master/doc/EthOS.md). Example is for FrSKY's EthOS, but any OpenTX/EdgeTX radio is basically the same.

2. This head tracker is only a "transmitter", it connects over Bluetooth to a master radio (or any other device) that supports PARA wireless trainer protocol. You may have Arduino Nano BLE connected to your radio that acts as a "receiver". That's fine, you need to configure _it_ to connect to XIAO BLE Sense board running this head tracker firmware. Or Cliff's head tracker firmware, if that is what you prefer.

I hope this clarifies things a bit and answers your questions!
Good luck!

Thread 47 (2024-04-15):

Adding Crossfire protocol?

ProfDrYoMan, 2024-04-15:
Hi,

adding crossfire would allow using ELRS as trainer link from head tracker to radio.

Recent versions of ELRS allow reprogramming RX as TX, so a tiny RX converted to TX could be used on the head tracker.

Edge-TX supports Crossfire as trainer input.

ysoldak, 2024-04-15:
I do not use Crossfire or ELRS myself, so chances are slim I ever implement this.
But I'm happy and open for contributions.

Just for me to have the full picture.
1) We are talking about radios w/o built-in bluetooth or with bluetooth but which does not speak PARA trainer protocol; otherwise no point to implement yet another link.
2) An ELRS receiver flashed and configured as transmitter (TX) will need to be connected to HeadTracker board (XIAO BLE Sense).

What's required from HeadTracker then? How shall it communicate with the ELRS TX board? Shall HeadTracker send data to serial port (RX/TX pins) in Crossfire format?

ProfDrYoMan, 2024-04-16:
Hi there,

1 Yes and no. I guess every TX that understands Crossfire will also understand para. Crossfire as input is only on EdgeTX afaik. So your reasoning is not wrong. Sometimes it is easier to fit an connect a small ELRS RX with ceramic antenna into the TX.
I see that BT is already in head tracker side. So it’s straight forward using BT on TX side.

2 The ELRS RX flashed as TX gets its data over serial in crossfire protocol.

One other project uses this to transmit directly to the gimbal with the ELRS PPM RX directly at the gimbal. With all mixing in the head tracker.

ysoldak, 2024-05-02:
The other project being https://github.com/dlktdr/HeadTracker perhaps?

I want to keep this Head Tracker's code compact and zero-configuration, this means all mixing and scaling have to happen in radio.

ProfDrYoMan, 2024-05-02:
Fully understand. Closing this one.

Closed 2024-05-02.

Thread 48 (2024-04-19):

permanent reset all 35 sec

boomerschnecke, 2024-04-19:
Having installed the latest SW to XIAO Sense board.
Using as Heattracker at Goggles.
Getting all 35sec periodically a reset of the board
Blue LED is switched off and Bluetooth modul at Radio side sets channels to 0 what means, that  Gimbal is resetted for a short time (around 1 sec)
XIOA is restarting and the Gimbal goes back to the needed position
Reproducable behaviour

ysoldak, 2024-04-22:
- Do you use version 2.5.1 from this repository?
- What is your radio transmitter?
- How do you connect head tracker to your radio?

boomerschnecke, 2024-04-22:
*yes, 2.5.1 latest version from your github page https://github.com/ysoldak/HeadTracker
*Radio = Radiomaster T16S
Seeduino XIAO BLE Sense with SW from https://headtracker.gitbook.io/head-tracker-v2.2 via Bluetooth and UART - Trainer Port conncetion

ysoldak, 2024-04-22:
So tell me is this ALL correct?
- On your goggles you have XIAO BLE Sense flashed with this repo FW 2.5.1;
- On your T16S radio you have another XIAO BLE Sense connected to the radio via UART trainer port, this XIAO has Cliff's firmware flashed and configured to run in "helper" or "rx" mode;
- Both XIAO boards do connect and talk via Bluetooth, but connection drops periodically (you say every 35 secs)

ALL this above true?
I, honestly, never tested such setup myself. All my radios have BT module built-in, so 🤷

Does the radio say "trainer lost" and "trainer recovered" when the disconnect happens?

boomerschnecke, 2024-04-29:
I did answer to you last week, but it seems something has gone wrong:
1) yes at XIAO BLE Sense there was the FW 2.5.1 installed (in the meantime I tried to use also the FW from Cliff)
2) yes, at T16s XIAO BLE Sense with SW from Cliff, connected via Bluetooth to XIAO BLE Sense at Goggles2. This one is connected via UARTexternal (AUX1) to the T16S, which is for this two channels in Trainer Mode setup
Thats true of course, otherwise I would not waste my time for giving you this information. I thought this might be interresting for you. From T16s there was coming no information concerning lost trainer of something like this. "Only" a "reset" to 0 for the servos all 35sec

ysoldak, 2024-05-02:
I would think this is the new feature of re-center on double tap misbehaving. Added in 2.5.0
But you say it does this weird stuff every 35 sec, that's really odd.

If you can, try connect a serial monitor (say from Arduino IDE) to the XIAO BLE board on goggles and see what's the output. Also or instead you may try and connect 128x32 little display to the board and see if axes jump there too.

I'm trying to understand where problem is, in this head tracker or in the helper module connected to your radio or somewhere in-between.

boomerschnecke, 2024-05-02:
Sorry, I do not have any of the mentioned additonal equipment available

Thetruesaint, 2024-06-22:
Hi guys!, me and a friend have a similar problem:
Seeduino XIAO BLE Sense with SW 2.5.1
Radio: TX16S MRKII with an ESP32 C3 supermini with proyect: https://github.com/dlktdr/BTWifiModule.git

Exactly 30 sec. after conection, it disconect from radio (Trainer signal Lost) and we see blue led flash again in the Xiao. In my case, some times, it`s reconnect inmidiatly... in my friend case, it always reconnect every 30 sec.

On the serial monitor, we can see axes movement, and no change in the output at the disconection event (86 to 87)

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

We still have to try to exchange Xiaos and see if the problem move or stay with the radio.

ysoldak, 2024-06-23:
@Thetruesaint thanks for report, see similar #52

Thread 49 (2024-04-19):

Is a base for DJI Goggles 2 existing

boomerschnecke, 2024-04-19:
Hi looking for a XIAO Base to be used for my DJI Goggles 2.
Or could I use one of the DJI Integra XIAO BLE Base for Goggles 2?
Could you please provide some detailed photos how this should be mounted and fitted?
Do I have to modify the foam? Or is it possible to use without faom modification?
Thank you

ysoldak, 2024-04-19:
Please see here and respective STL file

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

ysoldak, 2024-04-19:
DJI Integra and goggles 2 is the same. No foam modification needed.

boomerschnecke, 2024-04-19:
Thanks a lot for your quick reply. The issue is, that Goggles 2 is not having this "handle bar" at the top of the Goggles. So there is no possibility to click this "bar" in. Thats why a ask if something additional specially for Goggles 2 is existing. Or do I have to glue it on the foam?
https://store.dji.com/de/product/dji-goggles-2?vid=127611&from=search-result-v2&position=1&total_result=46
https://store.dji.com/de/product/dji-goggles-integra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
Have a look to the top in the middle of goggles

ysoldak, 2024-04-22:
Oh, my bad, I have Integra only and for some reason assumed Goggles 2 have top strap also.
Well, no then, nothing specific exists for Googles 2 yet. Will write here if/when we have a solution.

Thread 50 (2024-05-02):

PPM not working?

ysoldak, 2024-05-02:
Assembling here bug reports from @KPOPRC in no particular order.
Let's track the issue here.

>yuri! great project! did you stop supporting PWM on all the new releases. i can't get any TR signals via pwm from any of your releases. am i doing something wrong?

>Hello! it's looking like a great project. but the only stable release i can find that doesnt crash with in 3 sec, is 2.3.4 with pwm pin grounded. None of the other versions have red and green flashing with solid blue. regardless no head tracking values are making it to any of the TR channels. Did you guys stop supporting pwm? Please help. TR4 the channel goes up to -90%. all other tr channels kind of glitch at -7. when i unplug the trainer cable, i get an audible "trainer single lost". Any version after 2.3.4, no trainer signal is output via pin d10. D8 is grounded.

>Hello! After version 2.4 pwm doesn't recognize via my radio. But all UF2 files have never worked all the way down to 2.5.0. None of the TR channels carry any head tracking values. After 2.4 the board only flashes red. Can you help with this? I'd love to get these 2 head trackers working with pwm as my radiomaster doesn't have bluetooth.

ysoldak, 2024-05-02:
In your messages you probably mean PPM when you write PWM.

Please make sure you ordered correct XIAO board. You want XIAO BLE Sense variant, i.e. the one with IMU.
The cheaper board that is called simply XIAO BLE, without "Sense" in name, it will not work.

KPOPRC, 2024-05-02:
hey. thanks for the reply. this is the sense varient. I believe.

On Thu., May 2, 2024, 5:47 a.m. Yurii Soldak, ***@***.***>
wrote:

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

ysoldak, 2024-05-02:
The issue turned out to be the wrong board indeed. For the head tracker to work, it needs IMU (Inertial Measurement Unit) that is only available on XIAO BLE Sense board. See that little black box down left.

Closing the issue.

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

KPOPRC, 2024-05-02:
thanks for the help. I did notice that even with out the imu. I was still
getting a trainer signal. but for the latest releases no tr signal was out
put. I assume this is still a 'wrong board problem'. I'll let you know how
it goes with the new boards. they'll be here tomorrow. thanks for your
time.

k

On Thu., May 2, 2024, 2:19 p.m. Yurii Soldak, ***@***.***>
wrote:

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

Closed 2024-05-02.

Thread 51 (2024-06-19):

Two Seeeduino XIAO BLE Sense

bodychmarcin, 2024-06-19:
Hi. Is it possible to connect two modules together? one as a transmitter and the other as a receiver installed in TARANIS which sends the received data to the PPM pin?

ysoldak, 2024-06-23:
Not at the moment, not for two XIAO BLE Sense boards.
Some however try to use ESP32 C3 board on the radio side, and have issues unfortunately, see #48 and #52

I'll try and implement receiver on XIAO BLE board, eventually. No time frame though.

bodychmarcin, 2024-06-23:
Lack of time is very understandable for me :-) generally it doesn't have to be the same board, it can be anything else like esp32.  Tracker 2.2 as a receiver was mentioned in some threads, but as a BLE receiver for PPM it is too advanced and I had a problem with it.  I used ESP32 to connect to your firmware with the Xiao board, the connection was not broken even for a moment, and it was running for over an hour.  The problem is that I don't understand and I don't know the uuid structure and data, and therefore I don't know "golang".  That's why I started this thread.  Best regards, my friend.

bodychmarcin, 2024-06-28:
I wrote a program based on opentxbt that connects to seeduino, it works fine, nothing interrupts the connection, I receive data and send ppm.
Question: I'm curious, is it possible to implement client subscription in seeduino?

ESP32 BT Client, GPIO short to Ground -> sends bool (true or false)
XIAO BT server, receives data bool, if true -> Reset orientation

It is more convenient to do this with a monostable rc switch than to take your hand off to tap twice or look for a button soldered to the XIAO GPIO.

RDM3DGit, 2024-06-28:
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

Can you share link to your code?

bodychmarcin, 2024-07-01:
> Can you share link to your code?

I think so, but I would like to wait until ysoldak could create an additional characteristic, e.g. fff7, in which the client can save bool data, if xiao receives true, it will reset the orientation.

ysoldak, 2024-07-01:
Yes, good idea, @bodychmarcin!
Definitely we can have such extension to BT, add a characteristic. This will not be a strict PARA anymore, no problem though, since backwards compatible still.
Any known implementation/characteristic number for reset orientation? So we don't invent a wheel but just follow them?

bodychmarcin, 2024-07-01:
> Tak, dobry pomysł,@bodychmarcin! Zdecydowanie możemy mieć takie rozszerzenie do BT, dodać cechę. Nie będzie to już ścisła PARA, nie ma jednak problemu, ponieważ nadal jest kompatybilny wstecz. Jakiś znany numer implementacji/charakterystyki dla orientacji resetowania? Czyli nie wymyślamy koła, tylko po prostu za nimi podążamy?

I don't know the language, so I have to ask you about it.  I think you can add another number fff7.  What do you think about it?  unless it's a feature outside the Para structure.  I have ESP32C3 and the monostable switch is physically disconnected from the device and connected to the ESP32 GPIO.  if gpio is shorted, I would like it to send a bool to the xiao feature and reset it.  I don't want to take my hands off the radio :-)

ysoldak, 2024-07-01:
Yes, I think I understood you idea, adding one more characteristic shall be no problem.

So, the BT client sets a characteristic value to "true"; HT notices the value and resets its orientation + resets the characteristic value to default "false".

Shall work, need to test, obviously.

bodychmarcin, 2024-07-01:
I'll test it if you make a tag related to it :)

bodychmarcin, 2024-07-02:
I already managed to create a new service with new characteristics to handle the reset so as not to change PARA.  anyway, thanks for your willingness

Closed 2024-07-02.

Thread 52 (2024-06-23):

Continuosly lost and regain trainer conection (BT)

RDM3DGit, 2024-06-23:
Radio type: TX16S MK2 JB edition
Versions used:
- Radio FW: Edgetx 2.10.1 centurion cloud builded with bluetooth flag enabled
- ESP32 C3 Super Mini (Modified definition.h C3Mini URTS pins): cloned github repository, builded it and uploaded via VSCode
Connecting to: Xiao BLE sense HT with 2.5.1 FW

Expected beheavour: Conection between devices stays solid and uninterrupted.

Actual beheavour: Conection stablished perfctly, but after a minute or so the conection is lost and recovered instantanously. This continues to happen every 30 o 40 seconds continusly.

RDM3DGit, 2024-06-23:
C3 super mini terminal output during disconections and reconection:

BTCLIENT: scan start success
Disc BT Address 032BEC51FFBF, RSSI=-75, Addr Type=1
Disc BT Address F66A731161C3, RSSI=-80, Addr Type=1
Disc BT Address 1C72AA9511E4, RSSI=-80, Addr Type=1
Disc BT Address F66A731161C3, RSSI=-84, Addr Type=1
Connecting to F66A731161C3
Unable to connect to F66A731161C3, address not found in storage
I (716620) BTCLIENT: ESP_GATTC_CONNECT_EVT conn_id 0, if 3
I (716620) BTCLIENT: REMOTE BDA:
I (716620) BTCLIENT: f6 6a 73 11 61 c3
I (716620) BTCLIENT: Starting Service Scan
I (716630) BTCLIENT: open success
I (716910) BTCLIENT: update connection params status = 0, min_int = 10, max_int = 10,conn_int = 10,latency = 0, timeout = 70
I (717340) BTCLIENT: discover service complete conn_id 0
I (717340) BTCLIENT: SEARCH RES: conn_id = 0 is primary service 1
I (717340) BTCLIENT: start handle 23 end handle 65535 current handle value 23
I (717350) BTCLIENT: service found
I (717350) BTCLIENT: UUID16: fff0
I (717360) BTCLIENT: Get service information from remote device
I (717370) BTCLIENT: ESP_GATTC_SEARCH_CMPL_EVT
I (717370) BTCLIENT: Attr Count 5
I (717370) BTCLIENT: Found the Trainer Characteristic
I (717380) BTCLIENT: Subscribing for Notifications
I (717390) SETTINGS: Reading settings
I (717390) SETTINGS: Settings Read Successfully
I (717400) SETTINGS: No data differs, not writing to flash
I (717400) BTCLIENT: ESP_GATTC_CFG_MTU_EVT, Status 0, MTU 23, conn_id 0
I (717410) BTCLIENT: ESP_GATTC_REG_FOR_NOTIFY_EVT
I (717450) BTCLIENT: write descr success
W (747450) BT_GATT: gatt_rsp_timeout disconnecting...
W (747460) BT_HCI: hci cmd send: disconnect: hdl 0x1, rsn:0x13
W (747460) BT_APPL: gattc_conn_cb: if=3 st=0 id=3 rsn=0x16
E (747460) BTCLIENT: write char failed, error status = 85
W (747470) BT_HCI: hcif disc complete: hdl 0x1, rsn 0x16
I (747470) BTCLIENT: ESP_GATTC_DISCONNECT_EVT, reason = 22
Connecting to F66A731161C3
Unable to connect to F66A731161C3, address not found in storage
W (747970) BT_HCI: hcif disc complete: hdl 0x1, rsn 0x3e
W (748270) BT_HCI: hcif disc complete: hdl 0x1, rsn 0x3e
W (748740) BT_HCI: hcif disc complete: hdl 0x1, rsn 0x3e
W (749220) BT_APPL: gattc_conn_cb: if=3 st=0 id=3 rsn=0x3e
W (749220) BT_HCI: hcif disc complete: hdl 0x1, rsn 0x3e
I (749220) BTCLIENT: ESP_GATTC_DISCONNECT_EVT, reason = 62
E (749220) BTCLIENT: open failed, status 133

ysoldak, 2024-06-23:
Thank you @RDM3DGit for the great ticket!
I think it's the same as reported in #48 (or at least commented in)

TBH, I never did integration test with ESP32 C3 master, probably I should since I see more and more people use such combination.

ysoldak, 2024-06-23:
@RDM3DGit it looks like the problem is on ESP32 side though. BT stack seem to be misconfigured, etc.
See discussion here: https://devzone.nordicsemi.com/f/nordic-q-a/96053/esp32-gateway-disconnects-from-end-devices-nordic-after-30-seconds

I'm going to implement companion/receiver firmware for XIAO BLE Sense HT, on XIAO BLE [Sense] boards at first, then maybe support for ESP32 C3 comes too, but no promises. See #51

RDM3DGit, 2024-06-23:
Thank you very VERY much!!! for you quick response!

We are a group of RC FPV enthusiast here in Argetina looking foward to your HT project. Unfortunatly at this side of the world, it is very difficult and expensive for us to buy or even rich to some one that sells Arduino BLE 33 boards, thats way we are dealing with the hardware we could get here. (xiao ble sense on the HT side, and esp32 c3 super mini on the radio side).

I will read the discussion you pointed at, and keep trying.

@Thetruesaint FYI!

RDM3DGit, 2024-06-30:
Finally I go it to work without disconnections!!!! Im actually now connected since 40 minutes ago!!! The problem was at line 338 and 393 of bt_client.c of Cliff code where it was defined that gatt write requiered a response I changed them to not wait for a response and problem solved!!!
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

ysoldak, 2024-07-01:
Great! Thanks for sharing!
I trust you tell Cliff about this.

At this point, I’m not sure yet is this bug in Cliff’s code or mine… In other words, did you just hack Cliff’s code to work with my HT (so I’d better fix on my side, so no hacks needed) OR it was indeed a bug and shall be fixed there (your change applied for everyone).

RDM3DGit, 2024-07-01:
I think it's a bug on cliffs code. There's no reason for the client to wait for a response there.

Any way, I told him about this at his repository (closed the issue there too) but I don't think he is working on this code any more... (last update 2 years ago).

Thanks again, really love your code. I'm already using it.
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

Closed 2024-06-30.

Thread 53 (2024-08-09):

Recenter Button Not working with BLE Arduino on Remote Side

Velvethsaw, 2024-08-09:
So I we able to get a the Seeed Xiao sense working as a blue tooth head tracker withing minutes using this program. I think I am getting much less drift from my orginal setup. This is a wonderful solution, thank you so much!👌

I was previously using two Arduino BLE sense and Cliffs headtracker version. I was able to substitute the Seeed Xiao on the head tracker side and everything is working BUT the physcial centering switch I have wired to the remote side Arduino BLE is no longer working.

Anyway to fix this?

ysoldak, 2024-08-09:
Thank you, glad you like it!

I'll need to check how they send re-center signal back to HT unit, hopefully just setting a bluetooth attribute. If so, it will be real easy to implement. Just need to find time for that. Contributions are welcome!

ysoldak, 2024-08-09:
A hint: I know this is not something you used to and may not want to take your hand off your radio, but this HT can re-center w/o physical button -- just double-tap your goggles anywhere, and that shall re-center.

Velvethsaw, 2024-08-12:
Luckily I haven't not needed the recentering as much as before due to drift reduce on the Xaio board. Huge improvement. Unfortunately the system likes to drift at the most critical times during the flight so I need to keep my hands on the remote. I can lock the PWM positions with the flight control through my normal controls, then double tap my googles when I have a moment. But I would much rather have to option to have the additional button  to recenter right at my finger tops.

Thanks for the quick response. Bravo on the project!

dlktdr, 2024-08-19:
If you want to remote reset a 'R' character is written to Characteristic 0xAFF2,
https://github.com/dlktdr/HeadTracker/blob/6abe38db1ec6e71d9ade9d227abe93396ed7cb0b/firmware/src/src/btparahead.cpp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

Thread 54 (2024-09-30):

Add a magnetometer

Doncuppjr, 2024-09-30:
I think the seeed would support it, but could the firmware be updated to support a magnetometer for better pan support? I think we would also need some kind of configuration options for defining which axis takes that input, as currently the tracker can be put into almost any orientation and depending on where you mount it, an axis represents the pan.

ysoldak, 2024-09-30:
Do you have a link to a Seeed board with magnetometer?

Yes, this is by design -- you put the tracker on your googles any way you see best and then you map in your radio the channels accordingly. No need to configure also in HT.

Doncuppjr, 2024-09-30:
Maybe as both the seeed and mag are 3 axis, their could be a pairing pattern that would mitigate the need for configuration.

ysoldak, 2024-10-01:
Sure, this is doable and we can define how a magnetometer board shall be mounted relative to main xiao board so we can skip configuration.

The usefulness though escapes me, since:

>For a long time, Nano 33 BLE was the only board supported. It has an additional sensor, magnetometer, that head trackers usually use to eliminate pan drift. In practice, however, magnetometer adds more problems than solves. Magnetometer is very sensitive to environment and tricky to calibrate properly. In this project we do not use magnetometer and have a good zero-configuration automatic continuous gyro calibration instead to solve the drift problem. Already after first 5 seconds the calibration is good enough to stop the drift.

Can be a great fun addition. But only if we can make magnetometer auto-calibrate (I have some [experiments in that direction](https://github.com/ysoldak/magcal)). It's doable also, but as said probably is not worth the trouble.

Do you have problems currently with HT drifting on Xiao boards?

Doncuppjr, 2024-10-01:
I don't know if I actually have drift problems. I'm just getting started with the HT, and some things don't work quite like I expect. I might try playing with the weights and see if that resolves what I'm experiencing, but it seems like drift might also be a factor. Maybe the HT is detecting a double tap and resetting or something.

I do wonder how important calibration actually is for this though. I don't expect the HT would actually need to output the heading to anything, but rather just a reference to the magnetic field to avoid any potential drift of the accelerometer. 

On Tuesday, October 1, 2024 at 02:02:50 AM MDT, Yurii Soldak ***@***.***> wrote:

Sure, this is doable and we can define how a magnetometer board shall be mounted relative to main xiao board so we can skip configuration.

The usefulness though escapes me, since:

>  
> For a long time, Nano 33 BLE was the only board supported. It has an additional sensor, magnetometer, that head trackers usually use to eliminate pan drift. In practice, however, magnetometer adds more problems than solves. Magnetometer is very sensitive to environment and tricky to calibrate properly. In this project we do not use magnetometer and have a good zero-configuration automatic continuous gyro calibration instead to solve the drift problem. Already after first 5 seconds the calibration is good enough to stop the drift.
>

Can be a great fun addition. But only if we can make magnetometer auto-calibrate (I have some experiments in that direction). It's doable also, but as said probably is not worth the trouble.

Do you have problems currently with HT drifting on Xiao boards?

—
Reply to this email directly, view it on GitHub, or unsubscribe.
You are receiving this because you authored the thread.Message ID: ***@***.***>

Doncuppjr, 2024-10-13:
So I can confirm that I have a drift issue. I have the tracker inputs on a switch. I can sit down, double tap and everything is fine. Fly around a bit, hit the switch and my gimbal moves about 60 degrees to the left. Release switch, double tap, hit the switch, and everything is fine. Release switch, fly around a bit, hit the switch and the gimbal moves to the left again.

ysoldak, 2025-02-01:
@Doncuppjr I've spent some time in lab these days and successfully reproduced the drift behaviour.

Drift happens after fast movements. No drift when stationary.

I usually move my head around very slowly when flying, so did not notice the behaviour myself.
However, I was able to reliably reproduce the behaviour in my lab (board attached to a servo with servo tester and jerking it back and forth).

Full-fledged 9DOF IMU (with magnetometer) support may be required after all to fully eliminate the drift.

Meanwhile, I've played with sensor fusion parameters (see #57) and it seems like the HT handles fast movements much better now.

I'm going to release `v2.5.2` so you and anyone else interested can give it a try.

Leaving the ticket open until magnetometer support is finally added.

Doncuppjr, 2025-02-18:
Nice, I played around with wiring up a QMC5883 to the Xiao Sense. A basic arduino sketch shows that it works, but still some more work to do to make it a viable option.

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

```#include "LSM6DS3.h"
#include "Wire.h"
#include "QMC5883LCompass.h"

// Create an instance of class LSM6DS3
LSM6DS3 myIMU(I2C_MODE, 0x6A);  // I2C device address 0x6A

// Create an instance of the QMC5883LCompass class
QMC5883LCompass compass;

void setup() {
    Serial.begin(115200);
    Wire.begin();

    // Initialize LSM6DS3
    if (myIMU.begin() != 0) {
        Serial.println("LSM6DS3 Device error");
    } else {
        Serial.println("LSM6DS3 Device OK!");
    }

    // Initialize QMC5883
    compass.init();
    compass.setSmoothing(10, true);
    compass.setCalibration(-1150, 1250, -700, 1100, -750, 850);  // Adjust based on your calibration data

    Serial.println("QMC5883 initialized");
}

void loop() {
    // Accelerometer
    Serial.print("\nAccelerometer:\n");
    Serial.print(" X1 = ");
    Serial.println(myIMU.readFloatAccelX(), 4);
    Serial.print(" Y1 = ");
    Serial.println(myIMU.readFloatAccelY(), 4);
    Serial.print(" Z1 = ");
    Serial.println(myIMU.readFloatAccelZ(), 4);

    // Gyroscope
    Serial.print("\nGyroscope:\n");
    Serial.print(" X1 = ");
    Serial.println(myIMU.readFloatGyroX(), 4);
    Serial.print(" Y1 = ");
    Serial.println(myIMU.readFloatGyroY(), 4);
    Serial.print(" Z1 = ");
    Serial.println(myIMU.readFloatGyroZ(), 4);

    // Thermometer
    Serial.print("\nThermometer:\n");
    Serial.print(" Degrees C1 = ");
    Serial.println(myIMU.readTempC(), 4);
    Serial.print(" Degrees F1 = ");
    Serial.println(myIMU.readTempF(), 4);

    // Magnetometer
    Serial.print("\nMagnetometer:\n");
    compass.read();
    Serial.print(" X2 = ");
    Serial.println(compass.getX(), 4);
    Serial.print(" Y2 = ");
    Serial.println(compass.getY(), 4);
    Serial.print(" Z2 = ");
    Serial.println(compass.getZ(), 4);

    delay(1000);
}```

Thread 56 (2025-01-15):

How to add different or more inputs

Podex12, 2025-01-15:
First of all, I'm sorry if I'm being disrespectful of this following question/request. I have been wanting to make an additional input device for my ground station. I'm thinking of making a device consisting of multiple 2 or 3 position switch and a stick connected to esp32 (i have a lot of unused esp32 and esp8266) with its own power supply (probably 1s lipo). I plan to use the stick to control a camera gimbal pan and tilt rather than a magnetometer, while the switches is used for lights, auxiliary, autopilot/mission mode, etc. The problem is i don't know how could i send those inputs to my TX, mainly the Sofware side. My first guess is using the trainer port. So if you don't mind can you tell me how could i do this?
Thank you in advance

ysoldak, 2025-01-15:
Hi, @Podex12
Totally fine question, no worries!
So the simplest (single?) way to send data to you radio from an external device is via trainer port.
Most of radios have a physical trainer port (headphones jack) that accepts channels data encoded as PPM.
Some radios have Bluetooth built-in, that talks PARA wireless trainer protocol -- one can connect wirelessly to them (convenient) and send channel data that way.

We can talk in more details, feel free to reach out to me, search for Yurii Soldak on FB or just on internet and drop me a message!

ysoldak, 2025-01-16:
Nothing to do, this was a request for clarification.

Closed 2025-01-16.

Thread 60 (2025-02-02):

Sensitivity of double-click recognition

BG6PED, 2025-02-02:
Now it doesn't return to the center correctly even if I tap hard.

ysoldak, 2025-02-02:
@BG6PED you say it was working fine on `v2.5.1` and does not work on `v2.5.3` ?

ysoldak, 2025-02-02:
What board do you run on, XIAO BLE Sense or Nano 33 BLE?

ysoldak, 2025-02-02:
Fixed in `2.5.4`, @BG6PED please try.

Closed 2025-02-02.

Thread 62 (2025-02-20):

Sipeed M0Sense, does also work with?

deeph46, 2025-02-20:
Hi,

Does that board work with this headtracker?

Regards

ysoldak, 2025-02-20:
Hm, no. That board has totally different chip.

The code can be ported to work on any board with nRF52840 and IMU though.

deeph46, 2025-02-20:
Will be featured in the future maybe?

ysoldak, 2025-02-21:
If BL702 chip they use would be a clone of nRF, then maybe.
But it is not, so chances are very slim.

ysoldak, 2025-02-21:
I'm closing this now, ground research done, chip incompatible, no easy gains.

Closed 2025-02-21.

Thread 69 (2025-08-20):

Drift

TeodoroTechnology, 2025-08-20:
Hi, I’m experiencing an issue: whenever I reset the view using the reset button, it immediately starts drifting. I’ve tried keeping completely still for the 5 seconds after pressing reset, but as soon as I release the button, the view begins to drift again.

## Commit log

2021-01-26 Calibration sketch
2021-01-29 Calibration: use original Arduino_LSM9DS1 library, rather than v2 Some tweaks to the library needed though: rates shall be adjusted
2021-02-01 First order lag filter link
2021-02-01 Fixes #4: Case STL, STEP files and pictures
    [Clip.step, Clip.stl, Main.step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]
2021-02-01 Case pictures
2021-02-10 Use Madgwick sensor fusion + indicate Bluetooth status with blue led + extract configuration to config.h + switch to FemmeVerbeek's IMU library
    [Clip.step, Main.step, Main.stl]
2021-02-18 Fix initial heading Initialising Madgwick with acc and mag to calculate initial quaternion (rotation) + cosmetic and improved calibration for my boards
2021-03-15 adjust for board tilt and roll orientation
2021-03-15 Calculate board orientation on start - Fixes Madgwick initialization (tendency to drift, trying to reconcile) - Clean data on all three channels, regardless orientation Plus some minor fixes and refa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
2021-11-01 go: para works
2021-11-03 para: comments
2021-12-25 send values over para link
2021-12-25 period debug pin
2021-12-26 sleep a msec between imu readings, otherwise i2c hangs
2021-12-26 print out ble write error
2021-12-26 enable runtime mag calibration
2022-01-16 power led
2022-01-16 para: indicate connection status
2022-04-07 support XIAO BLE Sense board
2022-04-13 extract leds
2022-04-13 fix imu init
2022-05-08 trace version
2022-05-08 trace on unstable
2022-05-09 fix integer overflow in gyroscope calibration + some refactoring
2022-05-13 output angle range -180;+180 (was -45;+45) use mixer in radio to synchronize with respective servo throw
2022-05-13 Servo resistor mod docs
2022-08-08 Use UF2 bootloader on Arduino Nano 33 BLE boards
2022-08-08 button to reset center
2022-08-10 extract ppm output pin definition to pins.go
2022-08-15 Cases -- files, instructions and pictures.
    [Clip.step, Main.step, Nano33Ble-Clip.stl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]
2022-09-04 Fix board orientation issue Record original orientation quaternion and apply it to raw sensor values. This works better than initialising fusion with original quaternion, since depending on board ori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
2023-04-16 Xiao BLE case for 5 way joystick and wiring photo
    [XiaoBle3Case.stl, XiaoBle3Lock.stl]
2023-04-16 Better wiring image
2023-04-19 Micro Camera Gimbal pics and links
2023-04-25 Wiring diagram in Fritzing
    [xiao-ble-wiring.fzz]
2023-04-25 Avoid heap alloc in bt interrupt handler uses patched version of bluetooth lib
2023-05-25 Bluetooth disclaimer
    Apparently, not all Bluetooth modules work with the current Bluetooth stack of the head tracker. Removed link to the Tx16s Bluetooth installation instruction. It mentions the module that is known not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
2023-05-25 Link to proper PARA wireless module
2023-05-26 Replace link to instructables with link to discussion
    Discussion about options for radios w/o built-in PARA wireless trainer.
2023-09-12 Xiao BLE: High charge current (#33)
    * xiao-ble: high charge current
    * build: store artifacts
2023-12-09 Switch to TinyGo 0.30.0 and Go 1.21 (#37)
    and bump dependencies
2023-12-11 Calibration docs
2023-12-11 Store calibration to flash
2023-12-13 Fix condition in imu
2023-12-13 Calibration visulalisation
2023-12-13 Show Loading... when previous calibration exists
2024-01-20 Show battery voltage on splash screen
2024-01-20 Wiring diagram with battery
    [xiao-ble-wiring.fzz]
2024-01-21 Update wiring diagram
    [xiao-ble-wiring.fzz]
2024-03-11 case: STL and F3D files for assorted cases + documentation.
    [BDI Adpater Xiao Ble Button.stl, BDI Adpater Xiao Ble Case.stl, BDI Adpater Xiao Ble Lock.stl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]
2024-03-14 case: a version of bracket for Integra with thinner foams
    [DJI Integra Xiao Ble Base Forward.stl]
2024-05-20 docs: Outputs when servos wired via flight controller
2025-02-01 fix: adjust IMU sample rate and use 10ms ticker in main loop (#57)
    Also collect garbage often to avoid long unpredicted pauses.
    This all makes sensor fusion algorithm work much better.
2025-02-01 fix: nano-33-ble IMU sample rates (#59)
2025-05-09 fix: stable period in main loop + debug pins (#64)
    * fix: stable period in main loop + debug pins
    * fix: use common pin notation for debug pins
    * fix: update display on start
2025-06-19 fix: avoid alloc when reading double-tap (#67)
    * fix: avoid alloc when reading double-tap
    * trace: print heap usage
2025-10-17 chore: bump deps (#71)
    * chore: bump deps
    * sync with latest drivers
2025-10-17 fix: no garbage collection, as new drivers don't allocate on heap (#72)
2025-10-17 fix: handle IMU configuration errors (#73)
2025-10-30 XIAO Micro Case (#74)
    [xiao-micro-case-base.stl, xiao-micro-case-lid.stl]
2025-11-09 A 'Wired' version of the case. (#75)
    [xiao-micro-case-base-wired.stl, xiao-micro-case-lid-wired.stl]
2025-11-21 para: Change name from "Hello" to "HT <Version>" (#79)
2025-12-21 fix: ensure timing (#84)
    It takes ~15ms to update 128x32 display over I2C, when it is connected.
    Shall update display less often (once every 100ms), also each iteration can't be less than 15ms, so reverting back to 20ms from optimistic 10ms that we had for quite some time.
2025-12-21 fix: nameless calibration offsets (#85)
    We have no idea what is roll, pitch and yaw -- board can be oriented randomly on start
2025-12-21 para: run in a separate thread + refactor (#86)
2025-12-24 para: remote factory reset and reboot (#88)
2026-01-13 para: avoid endless loop on set system attributes error (#91)
2026-01-15 para: remotely set device name (#93)
2026-01-17 para: set axis-to-channel mapping (#94)
    also: inversion and enable/disable of a mapping
2026-01-18 test: drift tester (xiao + pca9685 + servo) and gyro calibration tune (#96)
2026-01-27 gyro: calibration tune and drift tester fixes (#97)
2026-06-12 docs: Document Bluetooth remote control functionality
    Added Bluetooth remote control features and commands.
    Also clarified use of D2 pin to do factory reset.
